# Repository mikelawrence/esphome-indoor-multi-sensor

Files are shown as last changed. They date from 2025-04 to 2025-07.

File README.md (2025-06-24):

# ESPHome Indoor Multi-Sensor

<p align="center">
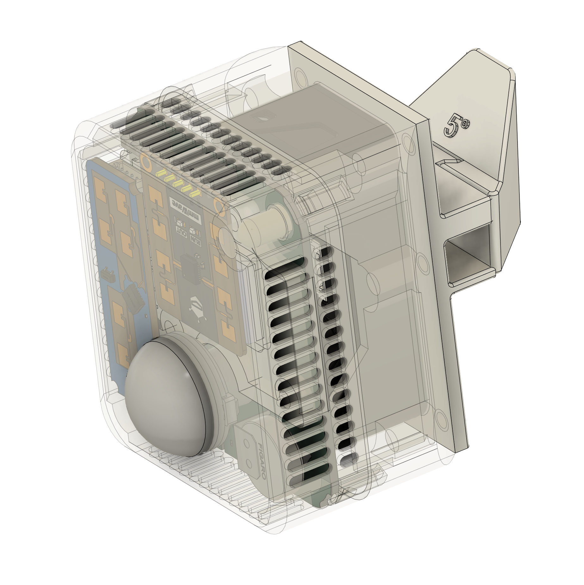
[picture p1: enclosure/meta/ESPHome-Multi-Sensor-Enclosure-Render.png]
  
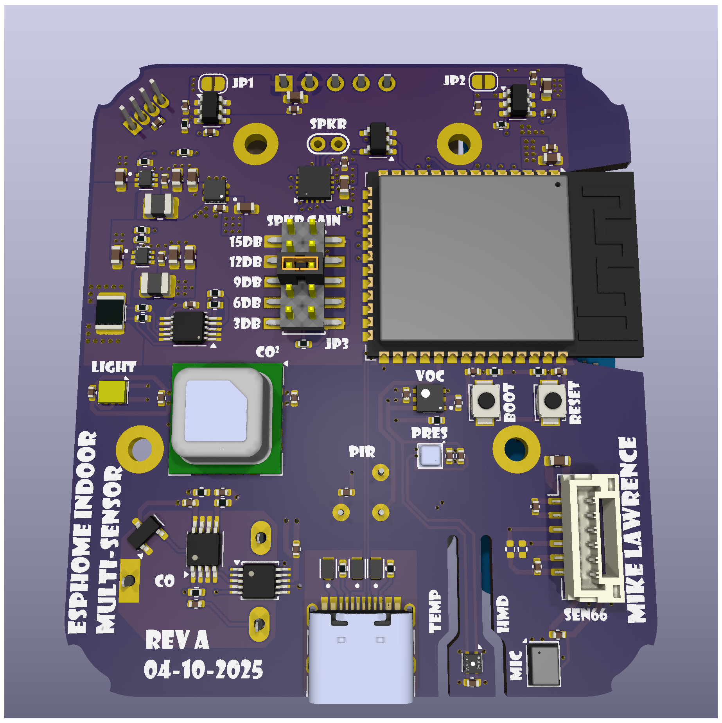
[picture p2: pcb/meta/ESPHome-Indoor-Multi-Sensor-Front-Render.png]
  
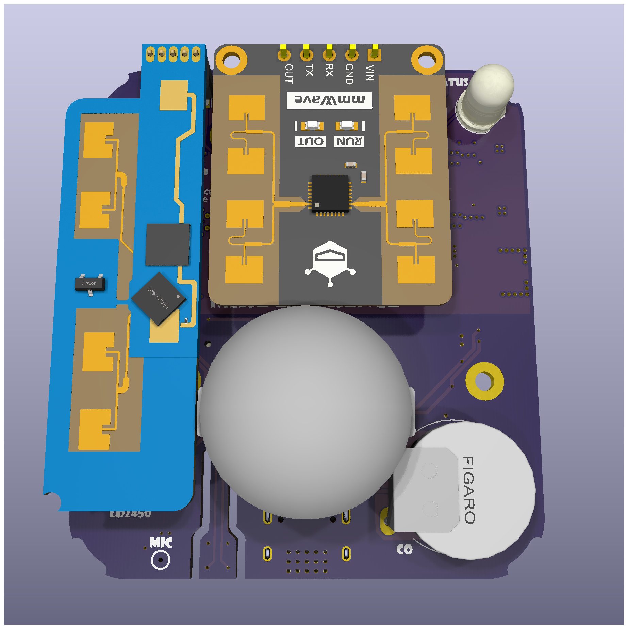
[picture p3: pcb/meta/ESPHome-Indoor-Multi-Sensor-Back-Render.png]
  
</p>

There are a lot of presence sensors using a combination of PIR and High Frequency Radar Human Presence Detectors to get a combination of quick response and low movement detection like when sleeping. Good examples of these types of sensor are the [Everything Presence One](https://shop.everythingsmart.io/products/everything-presence-one-kit) and [Roomsense IQ](https://www.roomsenselabs.com/). The later has a sensor module that you can add to support all sorts readings like Particular Matter (PM) Carbon Monoxide. But since I like to do everything myself. I started thinking about how I would approach this and more specifically what sensors did I want.

I settled on the following characteristics:

* ESP32-S3
* ESPHome software development
* USB-C Power
* Multiple options for Radar presence detection modules
  - Hi-Link LD2410B
  - Hi-Link LD2450
  - DFRobot C4001 (SEN609 and SEN610)
* PIR (Panasonic)
* Sensirion SEN66 All-in-One (Package A)
  - Temperature
  - Humidity
  - Particulate Matter (PM) 
  - CO₂
  - Volatile Organic Compound (VOC)
  - Nitrogen Oxide (NOX)
* Or individual Sensors (Package B)
  - Sensirion SHT4X Temperature and Humidity
  - Sensirion SCD4X CO₂
  - Sensirion SGP4X VOC and NOX
* Bosch BMP581 Pressure
* Figaro TGS5141 Carbon Monoxide (CO)
* AMS TSL2591 Light
* Microphone for sound levels
* A Speaker for alerts
* INA228 Power and Energy Monitor

## Status
* **Rev -** Has been fabricated and tested. I had JLCPCB fabricate the boards and I self assembled using a Home-Brew reflow oven by [Whizoo Controleo3](https://whizoo.com/). All circuits have been tested and found to be operational. 
* **Rev A** There was an issue with signal integrity on the I2C bus when communicating with the SEN66. To fix the problem I added stronger pullups and a new and dedicated I2C bus to the SEN66. Thus Rev A was born. I have not fabricated Rev A boards since I still have 6 Rev - boards left but the changes are minor and should be fine. Please let me know if you built Rev A and how it went.

## Design Decisions
### ESP32 and ESPHome
ESPHome is closely aligned with Home Assistant. In fact they are the same company. Home Assistant uses ESPHome for some of their hardware like the [Home Assistant Voice Preview Edition](https://www.home-assistant.io/voice-pe/) or [Bluetooth Proxy](https://esphome.io/components/bluetooth_proxy.html). I chose a newer ESP32-S3 for this design which also has Bluetooth support.

This project uses ESP32-S3-WROOM-2-N32R16V which has an enormous 32MB of flash and 16MB of octal PSRAM. These specs are way out of the normal range for an ESP32, so why? First I wanted to be able to store sounds directly on the unit itself mainly so it can sound out alerts even if Home Assistant is not connected. The PSRAM came along with the big Flash but it also has benefits. Sound pressure analysis likes more PSRAM and so does Bluetooth Proxying.

### Sensors
#### Radar based Human Presence Sensors
Both the Hi-Link sensors (LS2410B and LD2450) are supported by ESPHome directly but the DFRobot C4001 is not. I wrote an ESPHome External Component available [here](https://github.com/mikelawrence/ESPHome-Components?tab=readme-ov-file#esphome-c4001-external-component). The board has the LD2410 and LD2450 sharing the same physical space but the DFRobot C4001 can exist next to one of the LD sensors. I added circuitry so that you can choose which sensor to operate electrically. However enabling both simultaneously could result in strange behavior. After using the LD2450 for  bit I realized the the "just released" LD2450 ESPHome component has some short comings. Specifically there is no installation angle or flip-x-axis. So I added them in my version of the LD2450 ESPHome component [here] (https://github.com/mikelawrence/ESPHome-Components?tab=readme-ov-file#esphome-ld2450-external-component).

#### Sensor choices
The [SEN66](https://sensirion.com/products/catalog/SEN66) may be an expensive sensor package but it does it all, Temperature, Humidity, PM, CO₂, VOC and NOX. A tiny fan is primarily used for measuring PM but it also moves air by the temperature and humidity sensors making them fairly responsive. I call this Package A. If you choose not use the SEN66 you can populate the Package B individual sensors ([SHT4X](https://sensirion.com/media/documents/33FD6951/67EB9032/HT_DS_Datasheet_SHT4x_5.pdf), [SCD4X](https://sensirion.com/media/documents/48C4B7FB/67FE0194/CD_DS_SCD4x_Datasheet_D1.pdf) and [SGP4X](https://sensirion.com/media/documents/A056FE9C/61E970C2/Sensirion_Flyer_Gas_Sensors_Web.pdf)) to get Temperature, Humidity, CO₂, VOC and NOX. The only thing missing is PM.

#### Carbon Monoxide
For some reason CO sensors are not as common as CO₂ sensors. Most are expensive and have short life spans. The  Figaro TGS5141 is inexpensive and has a 10-year life span but it isn't a nice all-in-one with I2C interface. You have to add a transimpedance amplifier and then digitize the analog signal. I chose to add an ADS1115 16-bit ADC right next to the transimpedance amplifier instead of running analog signal across the board to the questionable ESP32 built in ADC. The ADS1115 also a has true differential Programmable Gain Amplifier on the input. This reduces the CO sensor circuit complexity. This sensor is not going to be very accurate but detection of CO in even low levels is probably a reason for concern. So even if not a safety sensor it can help.

I verified the CO circuit using CO Bump Gas. It doesn't calibrate, but it will prove that the sensor responds to the presence of CO. I used a small upside down container on my outside bench with the sensor I wanted to test inside. Squirting some bump gas inside with the thin straw showed that 4 out of 5 sensors responded to the gas. The 5'th that didn't respond had a solder bridge between two pins on the transimpedance amplifier. A quick removal of the solder bridge fixed the non-functioning sensor.

> [!WARNING]
> This CO sensor is not rated for safety nor is it particularly accurate. Use at your own risk! I still have UL listed (American) CO detectors as my main line of defense.

#### Pressure and Light
The [BMP581](https://www.bosch-sensortec.com/media/boschsensortec/downloads/datasheets/bst-bmp581-ds004.pdf) pressure sensor is primarily used as a barometric pressure sensor but it is sensitive enough for micro-pressure changes like when a door is closed. Pressure can also be used to compensate the CO₂ sensor in either the SEN6X or the SCD4X. Light is another measurement that may or may not be helpful but I included it. Keep in mind that this measurement is inside an enclosure thus has some significant limitations when it comes to accuracy.

#### Speaker and Microphone
The SEN66 takes up a lot of space so a small speaker is necessary. I choose a flat speaker from [Same Sky](https://www.sameskydevices.com/product/audio/speakers/miniature-(10-mm~40-mm)/cms-251437-24sp-x8) and started playing. My first attempts were pretty, flat, meaning these small speakers don't move a lot of air and in free space they have almost no volume. After doing some research it became clear, the speaker needs a enclosure. I was able to come up with a small 3D printed enclosure attached to the PCB itself. Man what a difference. This 2W speaker kicks some serious butt.

I threw in the microphone to measure sound levels. The intent is listen for noise as additional presence detection.

#### Power and Energy Monitor
The [INA228](https://www.ti.com/lit/ds/symlink/ina228.pdf) power and energy monitor can give instantaneous readings of voltage, current and power but it also measures energy over time (WHr).

### USB-C Power
I'm not using USB-C Power Delivery but I am expecting 5V @ 3A which is readily available if you have the right USB-C Power Brick. The PCB has the appropriate resistors on the CC pins which will request 5V @ 3A from a standard USB-C Power Brick. Testing shows slightly less than 1W for the Package A version and slightly less than 0.9 W for the Package B option as measured by the INA228. Quick measurements show about 8.1kWh/yr for Package A and 7.3kWh/yr for Package B. In Texas that is less than $1 per year.

## Enclosure
<p align="center">
  
</p>

More information is in the enclosure [README](enclosure/README.md) file.

## Operation
Expect an ESPHome YAML configuration soon.

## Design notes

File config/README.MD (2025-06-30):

# ESPHome Indoor Multi-Sensor Installation Configuration

Use this [webpage](https://mikelawrence.github.io/esphome-indoor-multi-sensor/) for installation and configuration.

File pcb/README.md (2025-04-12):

# ESPHome Indoor Multi-Sensor PCB
<p align="center">
  
  
</p>

The PCB is designed in [KiCad](https://www.kicad.org/). Fabrication and is tuned toward [JCLPCB](https://jlcpcb.com/). I chose not to use JLCPCB for assembly because they had a hard time with some the parts I included in this design. When I had the boards fabricated I also had them panelize two PCBs and produce a stencil for both for the panelized boards.

* **Rev -**: Is currently being fabricated. 

## Schematic
<p align="center">
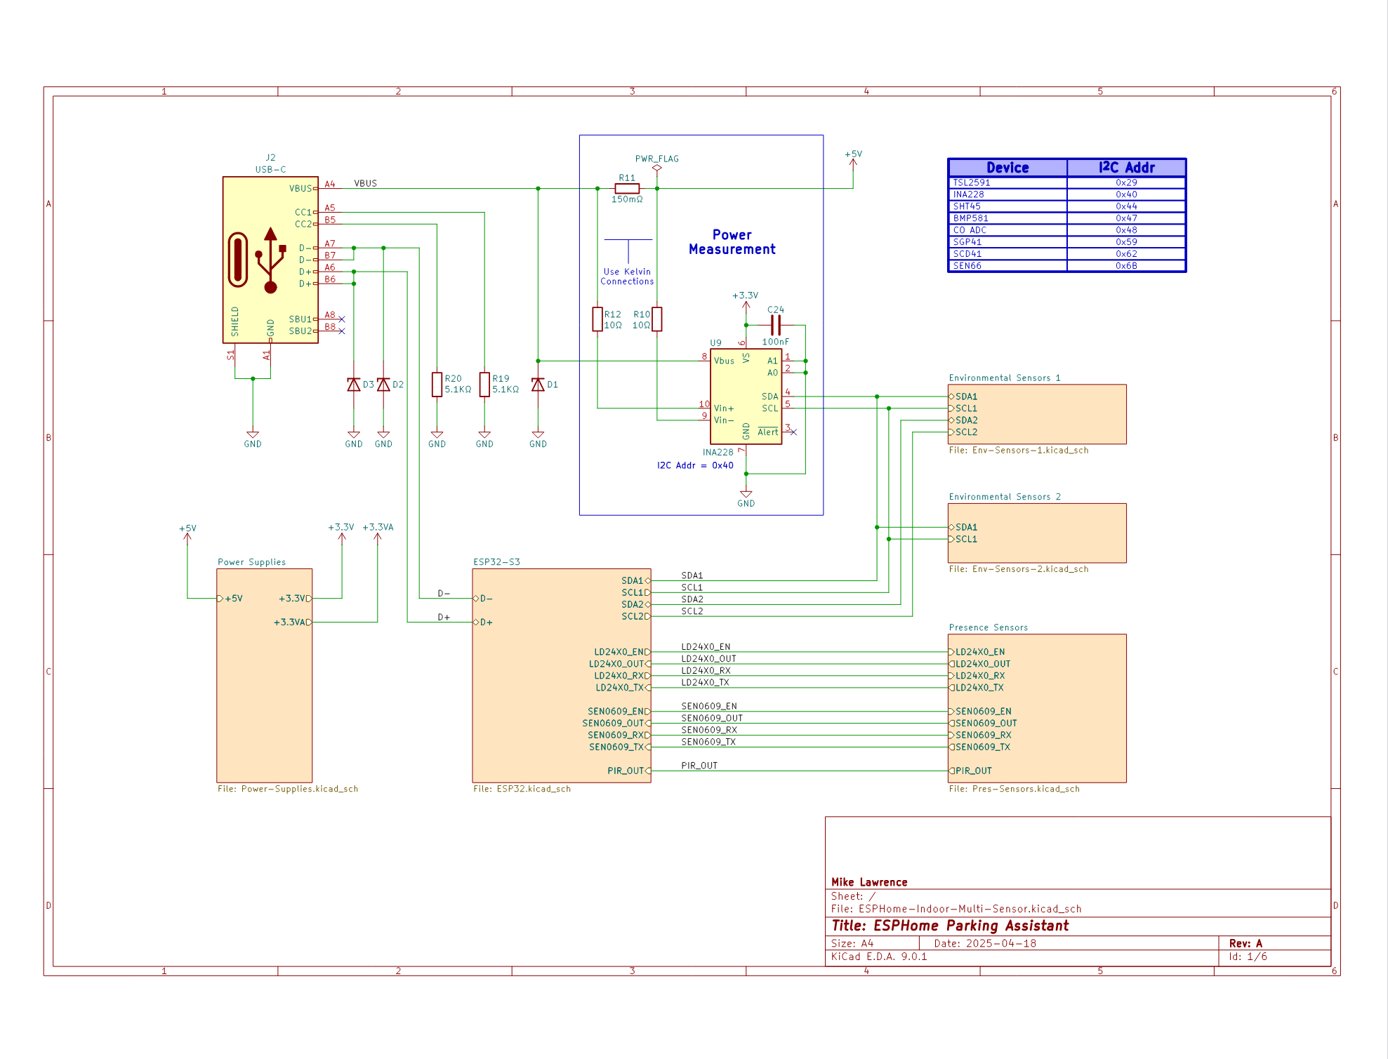
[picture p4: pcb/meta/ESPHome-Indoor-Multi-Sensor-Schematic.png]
     <br />
    Schematic
</p>

### Do Not Populate (DNP) Notes
When you use the SEN66 from Sensirion you don't need to install discrete sensor components ```U11```, ```U12```, ```U16```, ```C29```, ```C29```, ```C30```, ```C31``` or ```C43```.

## Bill of Materials
<p align="center">
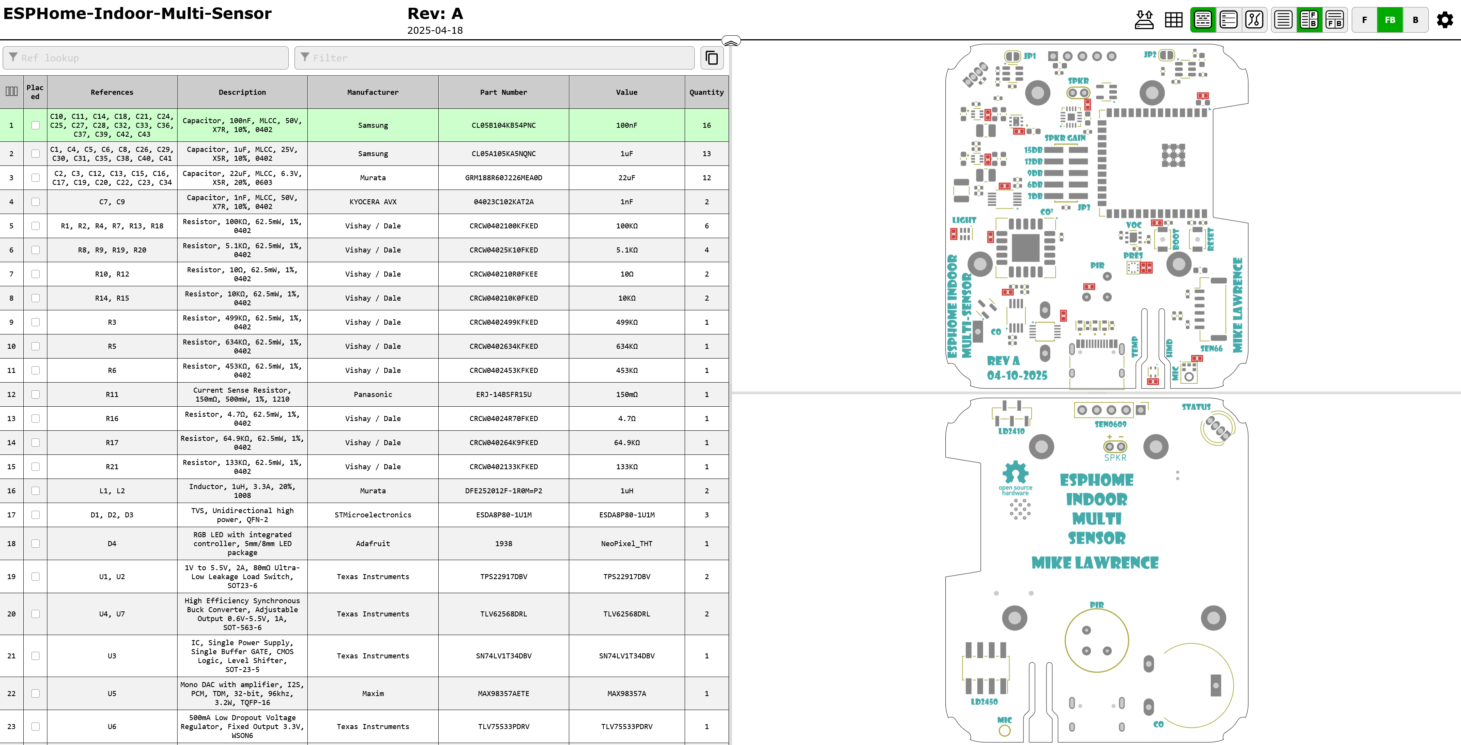
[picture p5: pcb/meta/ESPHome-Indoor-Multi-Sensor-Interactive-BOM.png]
     <br />
    Interactive BOM
</p>

## PCB Info
* 4 layer to support an additional ground plane and signal layer to reduce plane interruptions on the outer layers.
* There has been an attempt thermally isolate the SHT4X Temperature and Humidity Sensor but there are no guarantees.
* Dimensions are 52.5mm X 59.7mm.
* Requires oven reflow or hot air to assemble most components.

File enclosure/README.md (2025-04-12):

# ESPHome Parking Assistant Enclosure



This 3D printable enclosure is designed to go into a corner. It has a two-piece adjustable angle rear mount. Just change the ```Wall_Angle``` parameter. Both the speaker enclosure and back mount have TPU gaskets. The speaker gasket is to seal the enclosure and prevent vibrations from the speaker causing a buzzing sound. The TPU back mount gasket seals the SEN66 and provides a small amount of pressure to keep the SEN66 from moving.

The front body snaps into the back body and holds the PCB in place. A small cable connects the SEN66 to the PCB must be in place before snaps the bodies together.

The enclosure is designed in Fusion and is available [here](https://github.com/mikelawrence/ESPHome-Indoor-Multi-Sensor/raw/refs/heads/main/enclosure/ESPHome-Multi-Sensor-Enclosure.f3z).

If your are just looking for easy to print step file look in the ```3d-printing folder```. There a step file for each part and a nicely formatted Bambu Studio file with three plates ready to print.

## DFRobot C4001 SEN0609 Module
I couldn't find a step model of this Radar so I made one. Here is the [Fusion model](https://github.com/mikelawrence/ESPHome-Indoor-Multi-Sensor/raw/refs/heads/main/enclosure/DFRobot-C4001-SEN0609.f3z) and a [STEP model](https://github.com/mikelawrence/ESPHome-Indoor-Multi-Sensor/raw/refs/heads/main/enclosure/DFRobot-C4001-SEN0609.step).

## Hi-Link Electronics LD-2450 Module
The LD2450 Module I found were missing the front antennas and back header so I added these to the model from Hi-Link Electronics. Here is the [Fusion model](https://github.com/mikelawrence/ESPHome-Indoor-Multi-Sensor/raw/refs/heads/main/enclosure/HLK-LD2450-3D.f3z) and the [STEP model](https://github.com/mikelawrence/ESPHome-Indoor-Multi-Sensor/raw/refs/heads/main/enclosure/HLK-LD2450-3D.step).

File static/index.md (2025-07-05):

# ESPHome Indoor Multi-Sensor

You need to make two choices before programming the ESPHome Indoor Multi-Sensor. 

First is the Sensor package. You can either choose Package A, the Sensirion SEN6X sensor package which is an all-in-one sensor package. Or you can choose Package B which is a lower cost discrete sensor set that is missing particulate matter sensors. 

Next up is what type of radar sensor you plan on including. There are 4 options here, Hi Link LD2410 (My favorite), DFRobot C4001 (SEN0609 and SEN0610), Hi-Link LD2450 Multi-Target Multi-Zone (MTMZ) and the Hi-Link LD2450 Single-Target Single-Zone (STSZ). 

Each of these these builds include all supported sensors: pressure, light, sound level, power/energy monitor and speaker. If there are sensors you wish to not include, take control of the sensor and start configuring.

If you are really new to ESPHome I would recommend searching on Youtube for getting started videos.

## Installation

Use the buttons below to install pre-built firmware directly to your device via USB.

| Sensor Pkg | Radar LD2410 | Radar C4001 | Radar LD2450-MTMZ | Radar LD2450-STSZ |
|---|---|---|---|---|
| Pkg A | <esp-web-install-button manifest="firmware/sensor-pkg-a-ld2410.manifest.json"></esp-web-install-button> | <esp-web-install-button manifest="firmware/sensor-pkg-a-c4001.manifest.json"></esp-web-install-button> | <esp-web-install-button manifest="firmware/sensor-pkg-a-ld2450-mtmz.manifest.json"></esp-web-install-button> | <esp-web-install-button manifest="firmware/sensor-pkg-a-ld2450-stsz.manifest.json"></esp-web-install-button> |
| Pkg B | <esp-web-install-button manifest="firmware/sensor-pkg-b-ld2410.manifest.json"></esp-web-install-button> | <esp-web-install-button manifest="firmware/sensor-pkg-b-c4001.manifest.json"></esp-web-install-button> | <esp-web-install-button manifest="firmware/sensor-pkg-b-ld2450-mtmz.manifest.json"></esp-web-install-button> | <esp-web-install-button manifest="firmware/sensor-pkg-b-ld2450-stsz.manifest.json"></esp-web-install-button> |

<script type="module" src="https://unpkg.com/esp-web-tools@10/dist/web/install-button.js?module"></script> 

## Configuration

When you take control there are two sections you need to configure. In the ```substitutions:``` section you will find settings for many of the available sensors. Note: in yaml all substitutions are strings and should be in ```'single quotes'``` or  ```"double quotes"``` but the value may be interpreted as a float or a boolean value.

```yaml
substitutions:
  name: "sensor-pkg-a-c4001"
  friendly_name: "Indoor Multi-Sensor Pkg A Radar C4001"

  # Settings
  use_pir_in_presence: "true"
  # Status LED Configuration
  status_day_brightness: "0.5"
  status_night_brightness: "0.20"
  status_daytime_lux: "12.0"
  status_nighttime_lux: "7.0"
  # Temperature Configuration
  temperature_offset: "0.0"
  # Humidity Configuration
  humidity_offset: "0.0"
  # CO₂ Configuration
  co2_calibration_date: "Unknown"
  # CO Configuration
  co_temp_id: "temperature"
  co_offset: "0.0"
  co_sensitivity: "2.000e-9"
  co_manufacture_date: "Unknown"
  co_serial_number: "111111111111111111"
  # Automatically controlled Vent
  vent_ha_entity: fan.vent_id
  vent_use_humidity: "true"
  vent_use_co2: "true"
  vent_min_on_time: "15"
  vent_hum_on_trigger: "10.0"
  vent_hum_off_trigger: "2.5"
  vent_co2_on_trigger: "1100"
  vent_co2_off_trigger: "900"
```

The ```packages:``` section will allow you to disable sensors by commenting out it's included package. Note: do not comment out any Main Config Files.

```yaml
packages:
  remote_package_files:
    url: https://github.com/mikelawrence/esphome-indoor-multi-sensor
    refresh: 1h
    files:
      # Main Config Files
      - config/common/common.yaml
      - config/common/pkga-sen6x.yaml
      - config/common/radar-c4001.yaml

      # ADDITIONAL SENSORS
      # Carbon Dioxide (CO) - Figaro TGS5141 sensor
      - config/common/add-co.yaml
      # Energy Usage - INA2XX sensor to measure Voltage, Power and Energy Usage
      - config/common/add-ina2xx.yaml
      # Light Level - TSL2591 sensor
      - config/common/add-tsl2591.yaml
      # Barometric Pressure - BMP581 sensor
      - config/common/add-bmp581.yaml
      # Microphone - Adds Sound Level meter
      - config/common/add-microphone.yaml

      # FEATURES
      # SEN6X Pressure Compensation - Adds pressure compensation to SEN6X
      - config/common/feat-sen6x-press-comp.yaml
      # Automatic Vent - Use humidity and CO₂ control a bathroom vent
      - config/common/feat-auto-vent.yaml
```
### Settings

```yaml
  # Settings
  use_pir_in_presence: "true"
  # Status LED Configuration
  status_day_brightness: "0.5"
  status_night_brightness: "0.20"
  status_daytime_lux: "12.0"
  status_nighttime_lux: "7.0"
```

These are base sensor settings available for any configuration.

+ **use_pir_in_presence** (bool): You can disable the PIR motion detection from the presence sensor.
+ **status_day_brightness** (float): How bright is the Status LED during the day. Range is 0 to 1.0 where 1.0 means 100% brightness.
+ **status_night_brightness** (float): How bright is the Status LED during at night. Range is 0 to 1.0 where 1.0 means 100% brightness.
+ **status_daytime_lux** (float): The light level (lux) at which the Status LED will switch to daytime mode.
+ **status_nighttime_lux** (float): The light level (lux) at which the Status LED will switch to nighttime mode.
+ **temperature_offset** (float): The temperature sensor may have an offset due to environmental conditions. Use this to subtract out this error.
+ **humidity_offset** (float): The humidity sensor may have also have an offset. Use this to subtract out this error.
+ **co2_calibration_date** (string): Enter the last time the CO₂ was calibrated here and it will be reported as a text_sensor in the diagnostic section.

### Carbon Monoxide(CO) Configuration

```yaml
      # Carbon Dioxide (CO) - Figaro TGS5141 sensor
      - config/common/add-co.yaml
```

If you have included this package the CO sensor is enabled and there are substitutions you need to edit.

```yaml
  # CO Configuration
  co_temp_id: "temperature"
  co_offset: "0.0"
  co_sensitivity: "2.000e-9"
  co_manufacture_date: "Unknown"
  co_serial_number: "111111111111111111"
```

+ **co_temp_id** (ID): The accuracy of the CO sensor is improved with temperature compensation. This is the entity id of the temperature sensor to use.
+ **co_offset** (float): The CO sensor and circuit will have a offset. Use this to subtract out this error.
+ **co_sensitivity** (float): The CO has a default sensitivity of 2.000e-9 Amps/ppm. This should be the factory measured sensitivity as reported in the QR code on the sensor.
+ **co_manufacture_date** (float): From the QR code on the sensor. The sensor has a 10 year life expectancy. Reported as a text_sensor in the diagnostic section.
+ **co_serial_number** (float): From the QR code on the sensor. Not necessary but might come in handy down the road. Reported as a text_sensor in the diagnostic section.

### Automatically controlled Vent Configuration

```yaml
      # Automatic Vent - Use humidity and CO₂ control a bathroom vent
      - config/common/feat-auto-vent.yaml
```

If you have included this package the CO sensor is enabled and there are substitutions you need to edit.

```yaml
  # Automatically controlled Vent
  vent_ha_entity: fan.vent_id
  vent_use_humidity: "true"
  vent_use_co2: "true"
  vent_min_on_time: "15"
  vent_hum_on_trigger: "10.0"
  vent_hum_off_trigger: "2.5"
  vent_co2_on_trigger: "1100"
  vent_co2_off_trigger: "900"
```

+ **vent_ha_entity** (ID): This is the Home Assistant entity id of automatically controlled vent.
+ **vent_use_humidity** (bool): Enable humidity based control of the vent by setting this to ```true```.
+ **vent_use_co2** (bool): Enable CO₂ based control of the vent by setting this to ```true```.
+ **vent_min_on_time** (integer): This is the minimum on time for a vent for manual mode and how long the vent will stay on after the humidity or CO₂ returns to normal.
+ **vent_hum_on_trigger** (integer): This is the humidity level (%) rise from baseline that will turn on the vent. Baseline here is a fast exponential average (15 minutes). Showers usually have a sharp rise in humidity when first starting so a value of 10% rise in a few minutes is definitely a shower starting.
+ **vent_hum_off_trigger** (integer): This is the humidity level (%) from baseline that will turn off the vent. Baseline here is a slow exponential average (6ish hours). You want this number slightly above zero because sometimes the humidity level doesn't go back to where it was before a shower occurred quick enough. And even though the baseline average will eventually get there and cut off the vent it will have been on for hours.
+ **vent_co2_on_trigger** (integer): This is the CO₂ level that will cause the vent to turn on. Make 100-200 higher than ```vent_co2_off_trigger``` to give the vent a bit of hysteresis.
+ **vent_co2_off_trigger** (integer): This is the CO₂ level that will cause the vent to turn off.

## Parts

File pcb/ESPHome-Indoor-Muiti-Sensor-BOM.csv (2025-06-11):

Qty | Reference | Value | Description | DNP | Manufacturer | Part Number
13 | C1,C4,C5,C6,C8,C26,C29,C30,C31,C35,C38,C40,C41 | 1uF | Capacitor, 1uF, MLCC, 25V, X5R, 10%, 0402 |  | Samsung | CL05A105KA5NQNC
16 | C10,C11,C14,C18,C21,C24,C25,C27,C28,C32,C33,C36,C37,C39,C42,C43 | 100nF | Capacitor, 100nF, MLCC, 50V, X7R, 10%, 0402 |  | Samsung | CL05B104KB54PNC
12 | C2,C3,C12,C13,C15,C16,C17,C19,C20,C22,C23,C34 | 22uF | Capacitor, 22uF, MLCC, 6.3V, X5R, 20%, 0603 |  | Murata | GRM188R60J226MEA0D
2 | C7,C9 | 1nF | Capacitor, 1nF, MLCC, 50V, X7R, 10%, 0402 |  | KYOCERA AVX | 04023C102KAT2A
1 | D4 | NeoPixel_THT | RGB LED with integrated controller, 5mm/8mm LED package |  | Adafruit | 1938
3 | D1,D2,D3 | ESDA8P80-1U1M | TVS, Unidirectional high power, QFN-2 |  | STMicroelectronics | ESDA8P80-1U1M
1 | J1 | SEN66 | 6-Position, 1.25 mm pitch, Wire-to-Board connector |  | JST | BM06B-GHS-TBT
1 | J2 | USB-C | Connector, USB 2.0, 16P, Type-C, Receptacle |  | Phoenix Contact | 1332645
1 | J3 | SEN0609 | Generic connector, 2.54mm spacing, single row, 01x05 (TLW-105-06-T-S) |  | Samtec | CES-105-01-T-S
1 | J4 | LD2410 | Generic connector, 1.27mm spacing, single row, 01x05 |  | Samtec | RSM-105-02-S-S
1 | J5 | SPKR | Solder Holes for up to 24 ga wire |  | Same Sky | CMS-251437-24SP-X8
1 | J6 | LD2450 | Socket, 8 position, 2mm spacing, dual row, 02x04, SMT |  | Molex | 79109-1003
1 | JP3 | Gain | Header, 10 position, 2mm spacing, dual row, 02x05, SMT |  | Samtec | TMM-105-01-L-D-SM-P-TR
2 | L1,L2 | 1uH | Inductor, 1uH, 3.3A, 20%, 1008 |  | Murata | DFE252012F-1R0M=P2
1 | MK1 | ICS-43434 | TDK InvenSense MEMS Microphone, 24-bit I2S, 65 dBA SNR, LGA-6 |  | TDK InvenSense | ICS-43434
1 | Q1 | MMBFJ201 | 20mA min, 35V, 30mOhm max, 3-10V Vgs(off), N-Channel JFET, SOT-23 |  | Onsemi | MMBFJ201
1 | R3 | 499KΩ | Resistor, 499KΩ, 62.5mW, 1%, 0402 |  | Vishay / Dale | CRCW0402499KFKED
1 | R5 | 634KΩ | Resistor, 634KΩ, 62.5mW, 1%, 0402 |  | Vishay / Dale | CRCW0402634KFKED
1 | R6 | 453KΩ | Resistor, 453KΩ, 62.5mW, 1%, 0402 |  | Vishay / Dale | CRCW0402453KFKED
1 | R11 | 150mΩ | Current Sense Resistor, 150mΩ, 500mW, 1%, 1210 |  | Panasonic | ERJ-14BSFR15U
1 | R16 | 4.7Ω | Resistor, 4.7Ω, 62.5mW, 1%, 0402 |  | Vishay / Dale | CRCW04024R70FKED
1 | R17 | 64.9KΩ | Resistor, 64.9KΩ, 62.5mW, 1%, 0402 |  | Vishay / Dale | CRCW040264K9FKED
1 | R21 | 133KΩ | Resistor, 133KΩ, 62.5mW, 1%, 0402 |  | Vishay / Dale | CRCW0402133KFKED
6 | R1,R2,R4,R7,R13,R18 | 100KΩ | Resistor, 100KΩ, 62.5mW, 1%, 0402 |  | Vishay / Dale | CRCW0402100KFKED
2 | R10,R12 | 10Ω | Resistor, 10Ω, 62.5mW, 1%, 0402 |  | Vishay / Dale | CRCW040210R0FKEE
2 | R14,R15 | 10KΩ | Resistor, 10KΩ, 62.5mW, 1%, 0402 |  | Vishay / Dale | CRCW040210K0FKED
6 | R8,R9,R19,R20,R22,R23 | 5.1KΩ | Resistor, 5.1KΩ, 62.5mW, 1%, 0402 | DNP | Vishay / Dale | CRCW04025K10FKED
1 | SW1 | BOOT | Switch, SMD |  | Omron | B3U-1000P
1 | SW2 | RESET | Switch, SMD |  | Omron | B3U-1000P
1 | U3 | SN74LV1T34DBV | IC, Single Power Supply, Single Buffer GATE, CMOS Logic, Level Shifter, SOT-23-5 |  | Texas Instruments | SN74LV1T34DBV
1 | U5 | MAX98357A | Mono DAC with amplifier, I2S, PCM, TDM, 32-bit, 96khz, 3.2W, TQFP-16 |  | Maxim | MAX98357AETE
1 | U6 | TLV75533PDRV | 500mA Low Dropout Voltage Regulator, Fixed Output 3.3V, WSON6 |  | Texas Instruments | TLV75533PDRV
1 | U8 | ESP32-S3-WROOM-2-N32R16V | RF Module, ESP32-S3 SoC, Wi-Fi 802.11b/g/n, Bluetooth, BLE, 32-bit, 3.3V, onboard antenna, SMD |  | Espressif | ESP32-S3-WROOM-2-N32R16V
1 | U9 | INA228 | IC, High-Side or Low-Side Measurement, Bi-Directional Current and Power Monitor (0-85V) with I2C, SMBus-, and PMBus-Compatible Interface, VSSOP-10 |  | Texas Instruments | INA228AIDGSR
1 | U10 | TSL2591 | Light to digital converter, 2.7 to 3.6V Vdd, DFN-6 |  | AMS | TSL2591
1 | U11 | SGP41 | Indoor Air Quality Sensor, MOx based, DFN-6 |  | Sensirion | SGP41-D-R4
1 | U12 | SCD41 | Photoacoustic CO2 sensor, I2C, 2.4-5.5 V, High accuracy 400 - 5000 ppm |  | Sensirion | SCD41-D-R2
1 | U13 | BMP581 | Barometric Pressure Sensor, 24-bit, Low-power and Low-noise, SMD |  | Bosch Sensortec | BMP581
1 | U14 | MCP6042 | Dual Operational Amplifiers, Rail-to-Rail Input/Output, MSOP-8 |  | Microchip | MCP6042T-I/MS
1 | U15 | ADS1115 | Ultra-Small, Low-Power, I2C-Compatible, 860-SPS, 16-Bit ADCs With Internal Reference, Oscillator, and Programmable Comparator, VSSOP-10 |  | Texas Instruments | ADS1115IDGS
1 | U16 | SHT45 | Digital Humidity and Temperature Sensor, ±1%RH, ±0.1°C, I2C, 1.08-3.6V, 16bit, DFN-4 |  | Sensirion | SHT45-AD1B-R2
1 | U17 | EKMC1603111 | Passive Infrared (PIR) Motion Sensor, THT |  | Panasonic | EKMC1603111
1 | U18 | TGS5141 | Carbon Monoxide Sensor, Long life, THT |  | Figaro | TGS5141-P00
2 | U1,U2 | TPS22917DBV | 1V to 5.5V, 2A, 80mΩ Ultra-Low Leakage Load Switch, SOT23-6 |  | Texas Instruments | TPS22917DBV
2 | U4,U7 | TLV62568DRL | High Efficiency Synchronous Buck Converter, Adjustable Output 0.6V-5.5V, 1A, SOT-563-6 |  | Texas Instruments | TLV62568DRL

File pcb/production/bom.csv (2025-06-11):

Designator | Footprint | Quantity | Value | LCSC Part #
C1, C26, C29, C30, C31, C35, C38, C4, C40, C41, C5, C6, C8 | 0402 | 13 | 1uF | C52923
C10, C11, C14, C18, C21, C24, C25, C27, C28, C32, C33, C36, C37, C39, C42, C43 | 0402 | 16 | 100nF | C307331
C12, C13, C15, C16, C17, C19, C2, C20, C22, C23, C3, C34 | 0603 | 12 | 22uF | C77042
C7, C9 | 0402 | 2 | 1nF
D1, D2, D3 | TVS_ESDA25P35-1U1M | 3 | ESDA8P80-1U1M
D4 | LED_D5.0mm-4_RGB | 1 | NeoPixel_THT
J1 | JST_GH_BM06B-GHS-TBT_1x06-1MP_P1.25mm_Vertical | 1 | SEN66 | C189892
J2 | USB_C_Receptacle_HRO_TYPE-C-31-M-12 | 1 | USB-C
J3 | PinHeader_1x05_P2.54mm_Vertical | 1 | SEN0609
J4 | PinSocket_1x05_P1.27mm_Vertical_SMD_Pin1Right | 1 | LD2410
J5 | PinHeader_1x02_P2.00mm_Vertical | 1 | SPKR
J6 | PinSocket_2x04_P2.00mm_Vertical_SMD | 1 | LD2450
JP3 | SAMTEC_TMM-105-01-X-D-SM | 1 | Gain
L1, L2 | 1008 | 2 | 1uH | C435392
MK1 | InvenSense_ICS-43434-6_3.5x2.65mm | 1 | ICS-43434
Q1 | SOT-23 | 1 | MMBFJ201 | C891687
R1, R13, R18, R2, R4, R7 | 0402 | 6 | 100KΩ
R10, R12 | 0402 | 2 | 10Ω
R11 | 1210 | 1 | 150mΩ
R14, R15 | 0402 | 2 | 10KΩ
R16 | 0402 | 1 | 4.7Ω
R17 | 0402 | 1 | 64.9KΩ
R19, R20, R8, R9 | 0402 | 4 | 5.1KΩ
R21 | 0402 | 1 | 133KΩ
R3 | 0402 | 1 | 499KΩ
R5 | 0402 | 1 | 634KΩ
R6 | 0402 | 1 | 453KΩ
SW1 | SW_SPST_B3U-1000P-B | 1 | BOOT | C231329
SW2 | SW_SPST_B3U-1000P-B | 1 | RESET | C231329
U1, U2 | SOT-23-6 | 2 | TPS22917DBV | C2681320
U10 | AMS_TSL25911FN | 1 | TSL2591
U11 | XCDR_SGP40-D-R4 | 1 | SGP41
U12 | Sensirion_SCD4x-1EP_10.1x10.1mm_P1.25mm_EP4.8x4.8mm | 1 | SCD41
U13 | BMP581 | 1 | BMP581
U14 | MSOP-8_3x3mm_P0.65mm | 1 | MCP6042 | C627438
U15 | TSSOP-10_3x3mm_P0.5mm | 1 | ADS1115 | C37593
U16 | Sensirion_DFN-4_1.5x1.5mm_P0.8mm_SHT4x_NoCentralPad | 1 | SHT45
U17 | EKMC163111 | 1 | EKMC1603111
U18 | TGS-5141 | 1 | TGS5141
U3 | SOT-23-5 | 1 | SN74LV1T34DBV | C100024
U4, U7 | SOT50P160X60-6N | 2 | TLV62568DRL | C398372
U5 | TQFN-16-1EP_3x3mm_P0.5mm_EP1.23x1.23mm | 1 | MAX98357A
U6 | VREG_TLV75533PDRVR | 1 | TLV75533PDRV
U8 | ESP32-S3-WROOM-2 | 1 | ESP32-S3-WROOM-2-N32R16V
U9 | VSSOP-10_3x3mm_P0.5mm | 1 | INA228 | C2887910

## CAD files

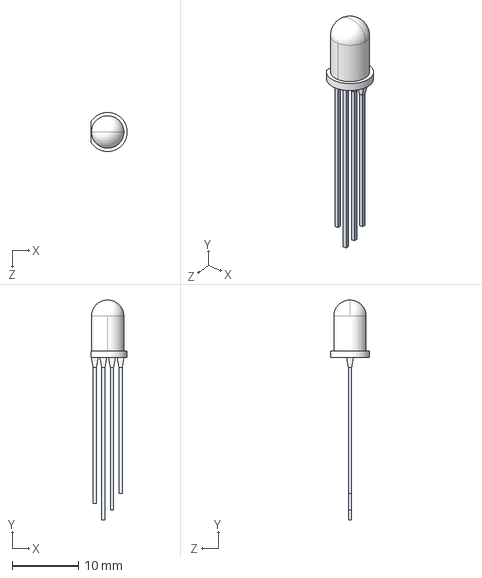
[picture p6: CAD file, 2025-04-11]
pcb/3dmodels/5mm RGB LED--3DModel-STEP-269445.STEP
5.50 x 33.2 x 5.89 mm

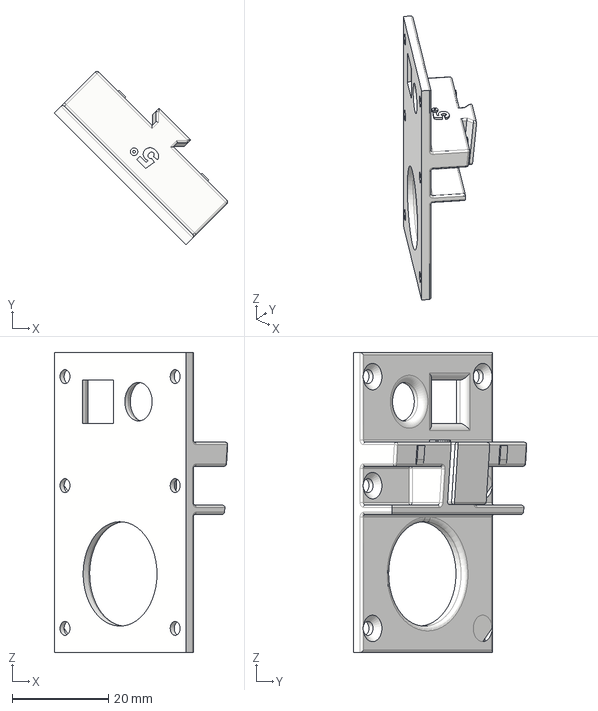
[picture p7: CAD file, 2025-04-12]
enclosure/3d-printing/ESPHome-Multi-Sensor-Enclosure-Back-Mount-5°.step
36.0 x 36.0 x 62.2 mm

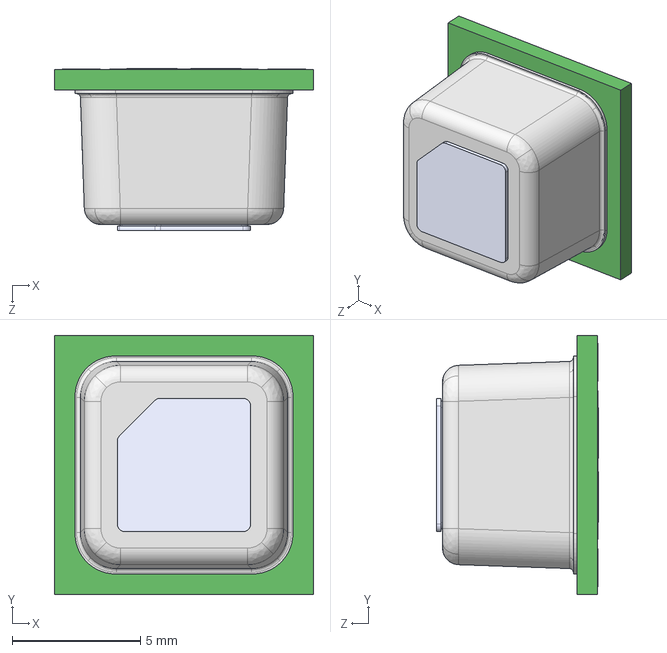
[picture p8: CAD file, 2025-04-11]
pcb/3dmodels/SCD41-D-R2--3DModel-STEP-369182.STEP
10.1 x 10.1 x 6.31 mm

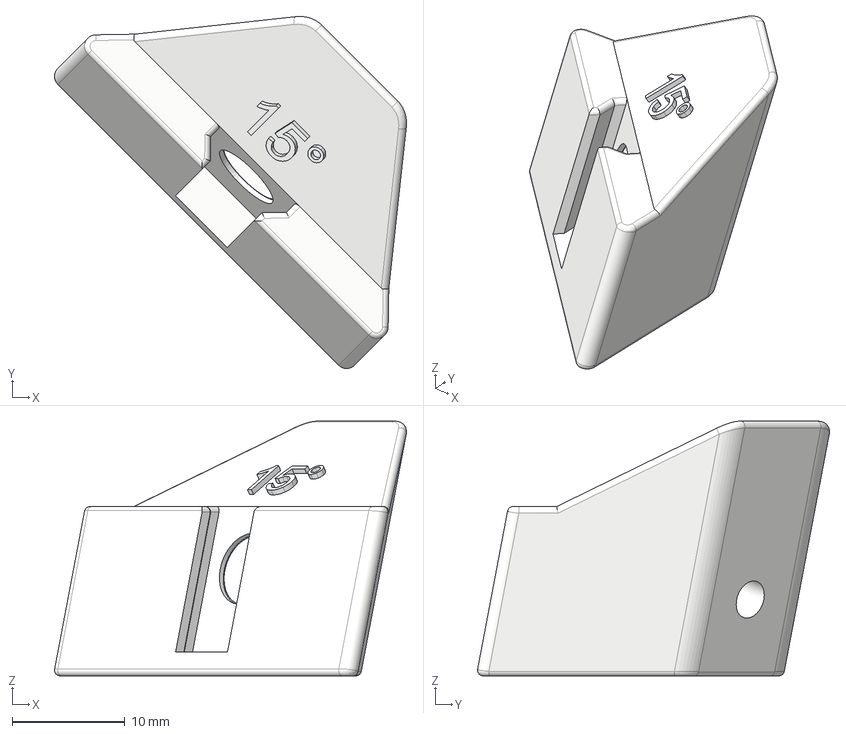
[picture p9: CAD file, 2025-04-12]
enclosure/3d-printing/ESPHome-Multi-Sensor-Enclosure-Corner-Mount-15°.step
31.2 x 31.2 x 22.6 mm

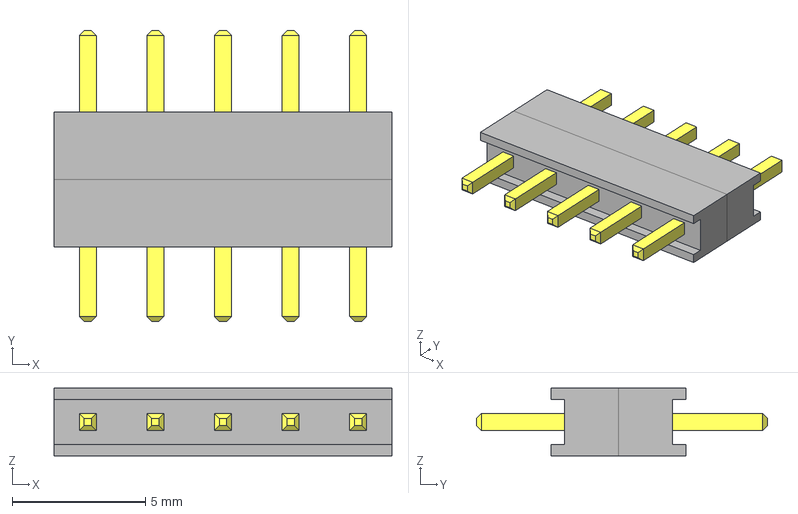
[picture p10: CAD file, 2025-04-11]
pcb/3dmodels/DW-05-07-T-S-200.stp
12.7 x 10.9 x 2.54 mm
ZW-05-07-G-S-200-110bbody
ZW-05-07-G-S-200-110_pins
ZW-05-07-G-S-200-110_top_body

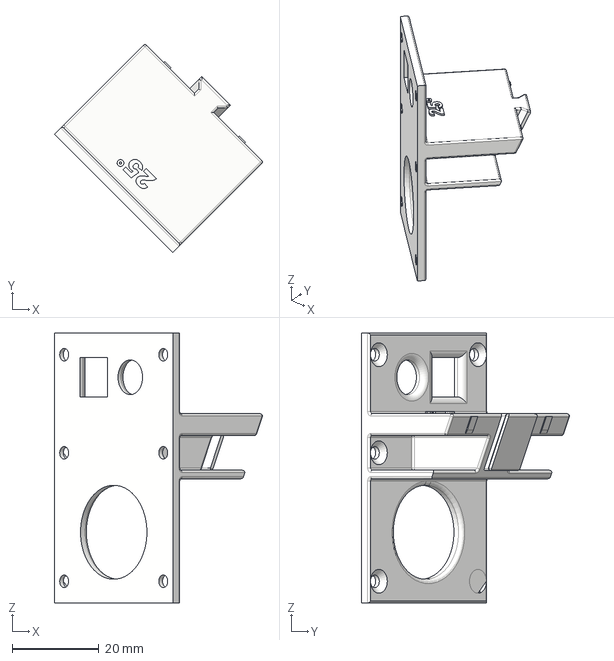
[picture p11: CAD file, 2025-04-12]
enclosure/3d-printing/ESPHome-Multi-Sensor-Enclosure-Back-Mount-25°.step
47.9 x 47.9 x 62.2 mm

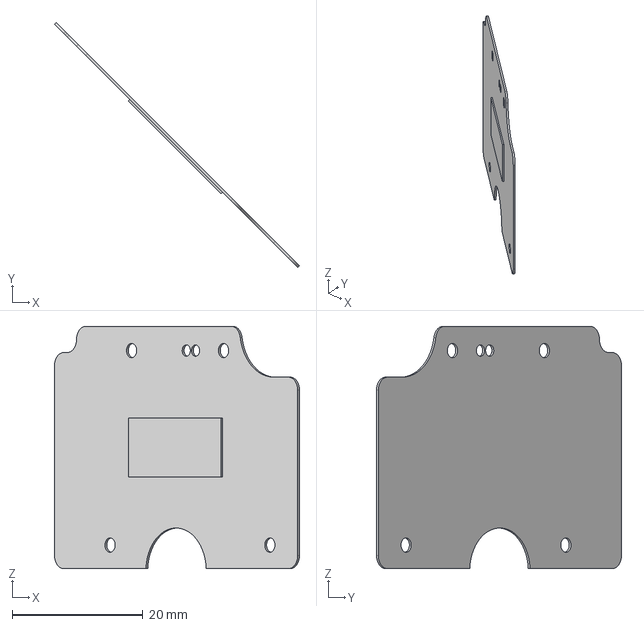
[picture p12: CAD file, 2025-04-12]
enclosure/3d-printing/ESPHome-Multi-Sensor-Enclosure-Speaker-Gasket-25mmx14mm.step
37.4 x 37.4 x 37.0 mm

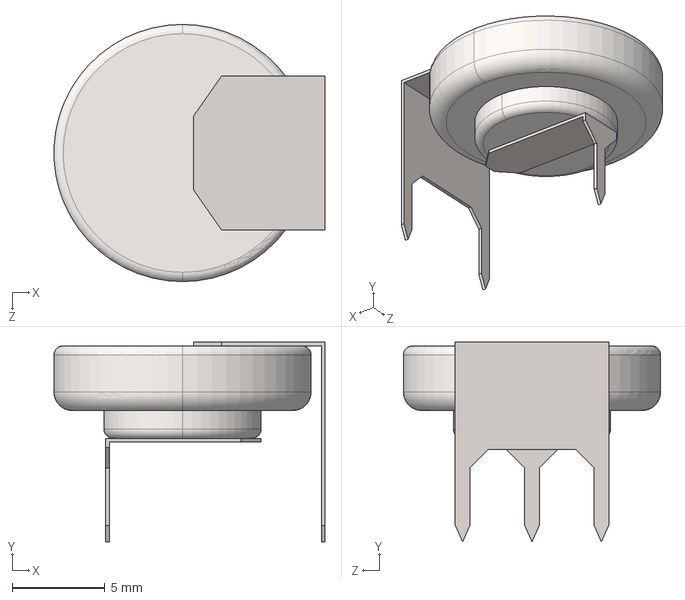
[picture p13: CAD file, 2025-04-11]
pcb/3dmodels/User Library-TGS5141.STEP
14.6 x 10.8 x 13.9 mm

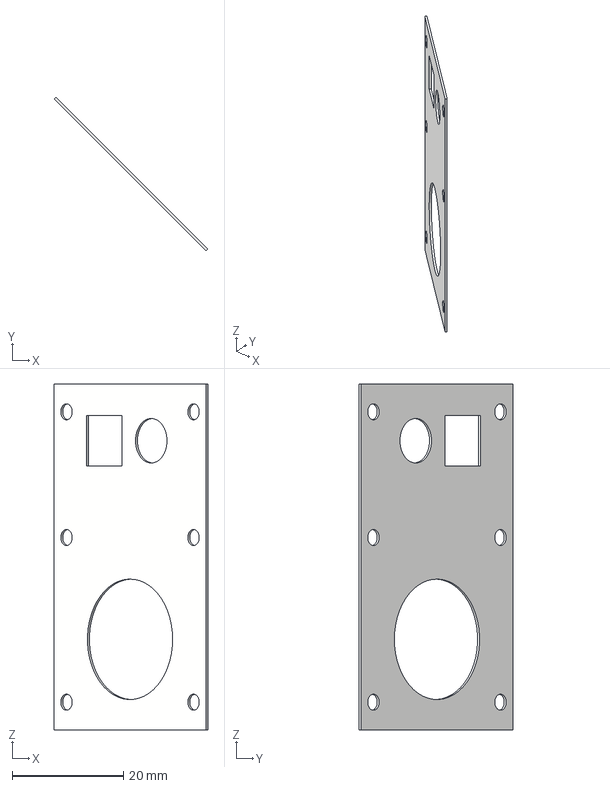
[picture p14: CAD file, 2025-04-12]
enclosure/3d-printing/ESPHome-Multi-Sensor-Enclosure-Back-Mount-Gasket.step
27.6 x 27.6 x 62.2 mm

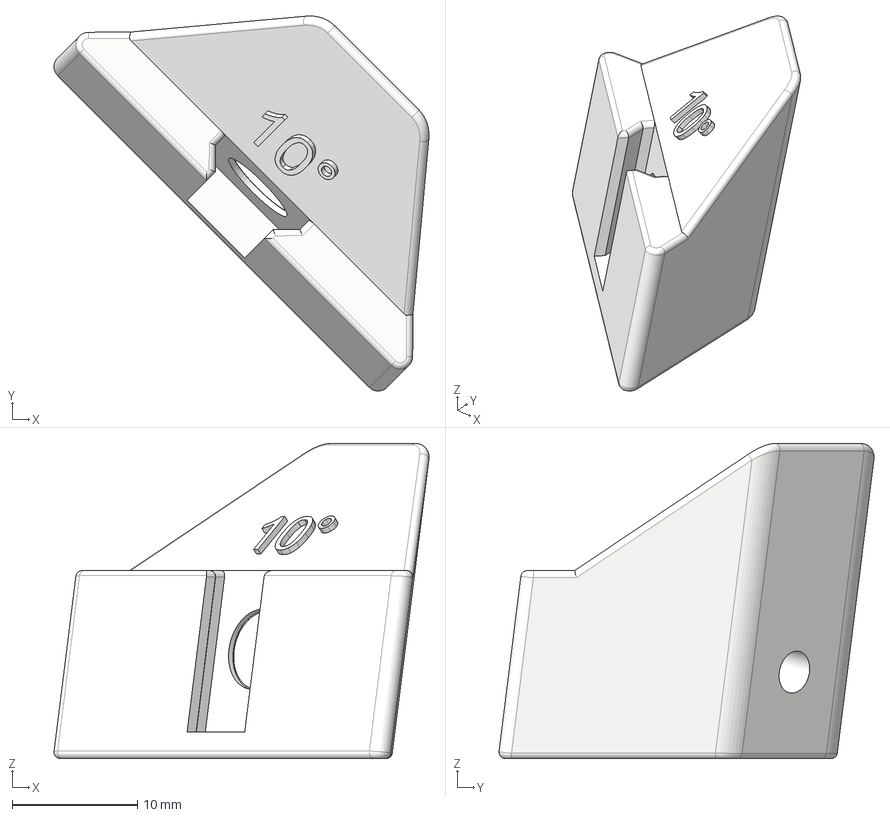
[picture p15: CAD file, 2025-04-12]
enclosure/3d-printing/ESPHome-Multi-Sensor-Enclosure-Corner-Mount-10°.step
29.9 x 29.9 x 25.1 mm

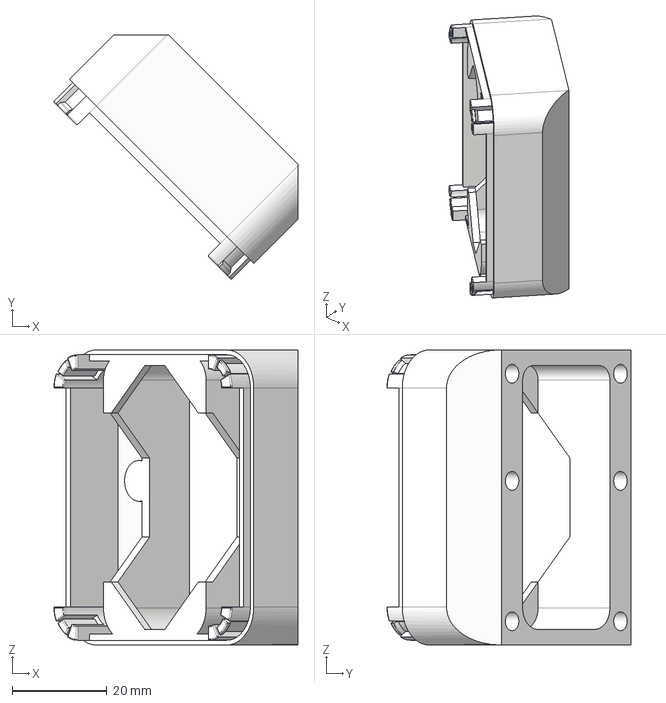
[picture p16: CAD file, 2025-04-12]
enclosure/3d-printing/ESPHome-Multi-Sensor-Enclosure Back Body.step
51.4 x 51.4 x 62.2 mm

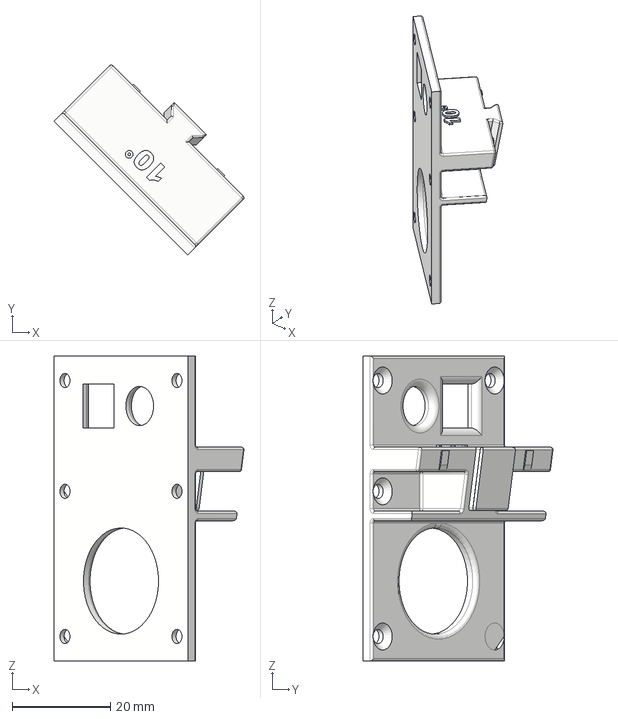
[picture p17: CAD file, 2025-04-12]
enclosure/3d-printing/ESPHome-Multi-Sensor-Enclosure-Back-Mount-10°.step
38.7 x 38.7 x 62.2 mm

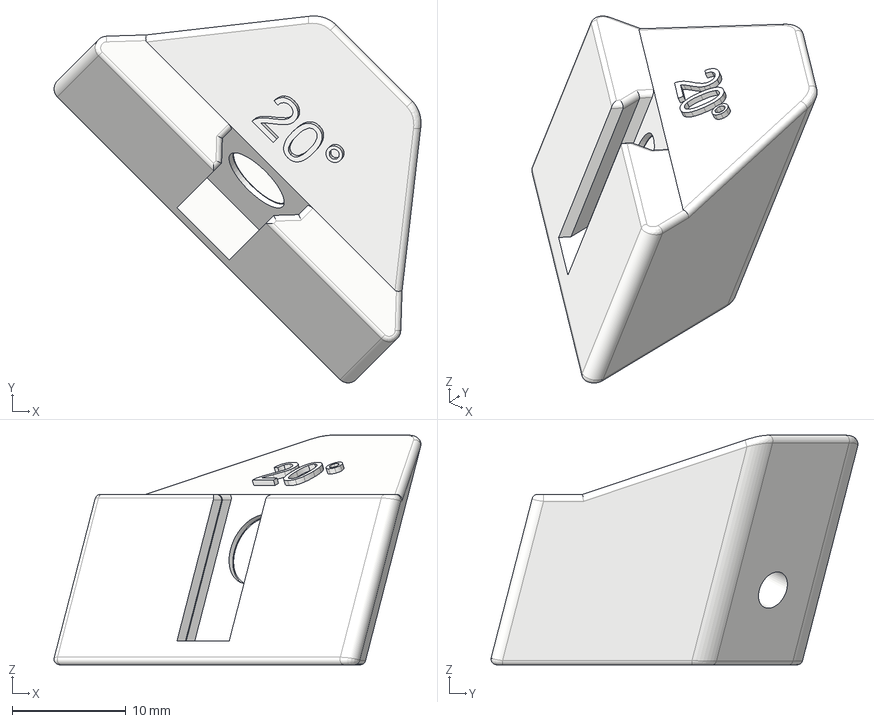
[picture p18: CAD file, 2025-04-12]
enclosure/3d-printing/ESPHome-Multi-Sensor-Enclosure-Corner-Mount-20°.step
32.3 x 32.3 x 20.2 mm

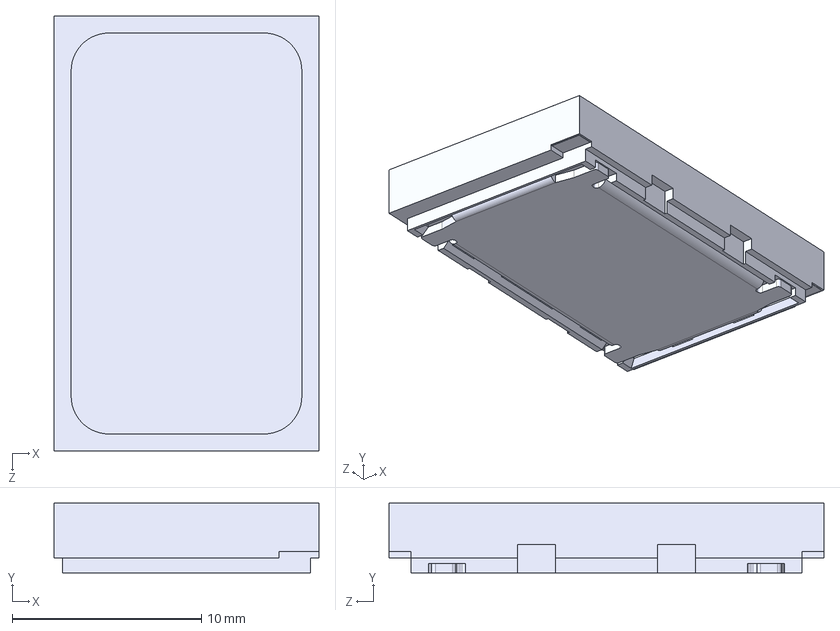
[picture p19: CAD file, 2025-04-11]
pcb/3dmodels/Same_Sky_CMS-321437-24SP-X8.step
14.0 x 3.70 x 23.0 mm

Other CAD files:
enclosure/3d-printing/ESPHome-Multi-Sensor-Enclosure-Bambu-Studio.3mf
pcb/3dmodels/DW-05-07-T-S-240.stp
enclosure/3d-printing/ESPHome-Multi-Sensor-Enclosure-Back-Mount-15°.step
pcb/3dmodels/RSM-105-02-S-S.stp
enclosure/3d-printing/ESPHome-Multi-Sensor-Enclosure Front Body.step
enclosure/3d-printing/ESPHome-Multi-Sensor-Enclosure-Back-Mount-20°.step
enclosure/3d-printing/ESPHome-Multi-Sensor-Enclosure-Corner-Mount-25°.step
enclosure/3d-printing/ESPHome-Multi-Sensor-Enclosure-Corner-Mount-5°.step
enclosure/3d-printing/ESPHome-Multi-Sensor-Enclosure-Speaker-25mmx14mm.step
pcb/3dmodels/55510-308TRLF--3DModel-STEP-554624.STEP
pcb/3dmodels/791091003.stp
pcb/3dmodels/86730.stp
pcb/3dmodels/CES-105-01-T-S.stp
pcb/3dmodels/DW-05-08-T-S-250.stp
pcb/3dmodels/ESP32-S3-MINI-1-N8--3DModel-STEP-1.STEP
pcb/3dmodels/HLK-2410B.step
pcb/3dmodels/MAX98357-TQFN-16.step
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

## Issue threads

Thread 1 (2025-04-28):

Cost question

fredmorais, 2025-04-28:
Hey,

I think this project looks really good and I am really looking forward to try it, but I have a question regards cost: can you share how much it cost to make the PCB + components?

It would be really helpful to understand how much each sensor will cost!

Best,

mikelawrence, 2025-04-28:
I didn't design for cost so this is not cheap. A full cost workup would take too long but here is some quick info.

10 PCBs from JLCPCB $40
SEN66 is about $55
ESP32 $7 You could choose a cheaper ESP32
C4001 $13
LD2410 $10
LD2450 $15
PIR $10
Pressure $6
SCD41 $25
SGP41 $10
SHT45 $6
CO sensor + circuit is about $15

Odds and ends is about $50 to $75

You can grab the BOM and import it to Mouser or Digikey to get a better idea of component cost.
Newark has the best price on the SEN66. If you use the SEN66 you don't need the SCD41, SGP41 or SHT45.

BTW I have checked out everything but the CO circuit. I have some bump gas coming with 200 ppm of CO to see if I can get the CO sensor to measure something. Also the Sound Level Meter software I was planning on using doesn't play well with other sound devices. Right now I can't get the Sound Level Meter and Speaker working at the same time. Both work separately though.

mikelawrence, 2025-04-28:
Something else to realize the SEN66 probably shouldn't be used in a bathroom, too much humidity. My wife also uses hairspray. I can't even begin to imagine what that would do to the sensor.

fredmorais, 2025-04-28:
Thanks for the info! One last question: I have been getting into circuit design but I am not able to reach this conclusion: if I removed some sensors that I do not find interesting (pressure, PIR, for example), would the sensor still work normally?

mikelawrence, 2025-04-29:
Yes, but as you remove sensors from the board you will need to remove them from the ESPHome YAML too. There isn't any one sensor that is dependent on another. You can remove the INA228 power sensor too but be sure to either keep R11 or short it. You can save money in other ways. Choose only one MMWave sensor, remove the power switch circuits and short the appropriate JPx.

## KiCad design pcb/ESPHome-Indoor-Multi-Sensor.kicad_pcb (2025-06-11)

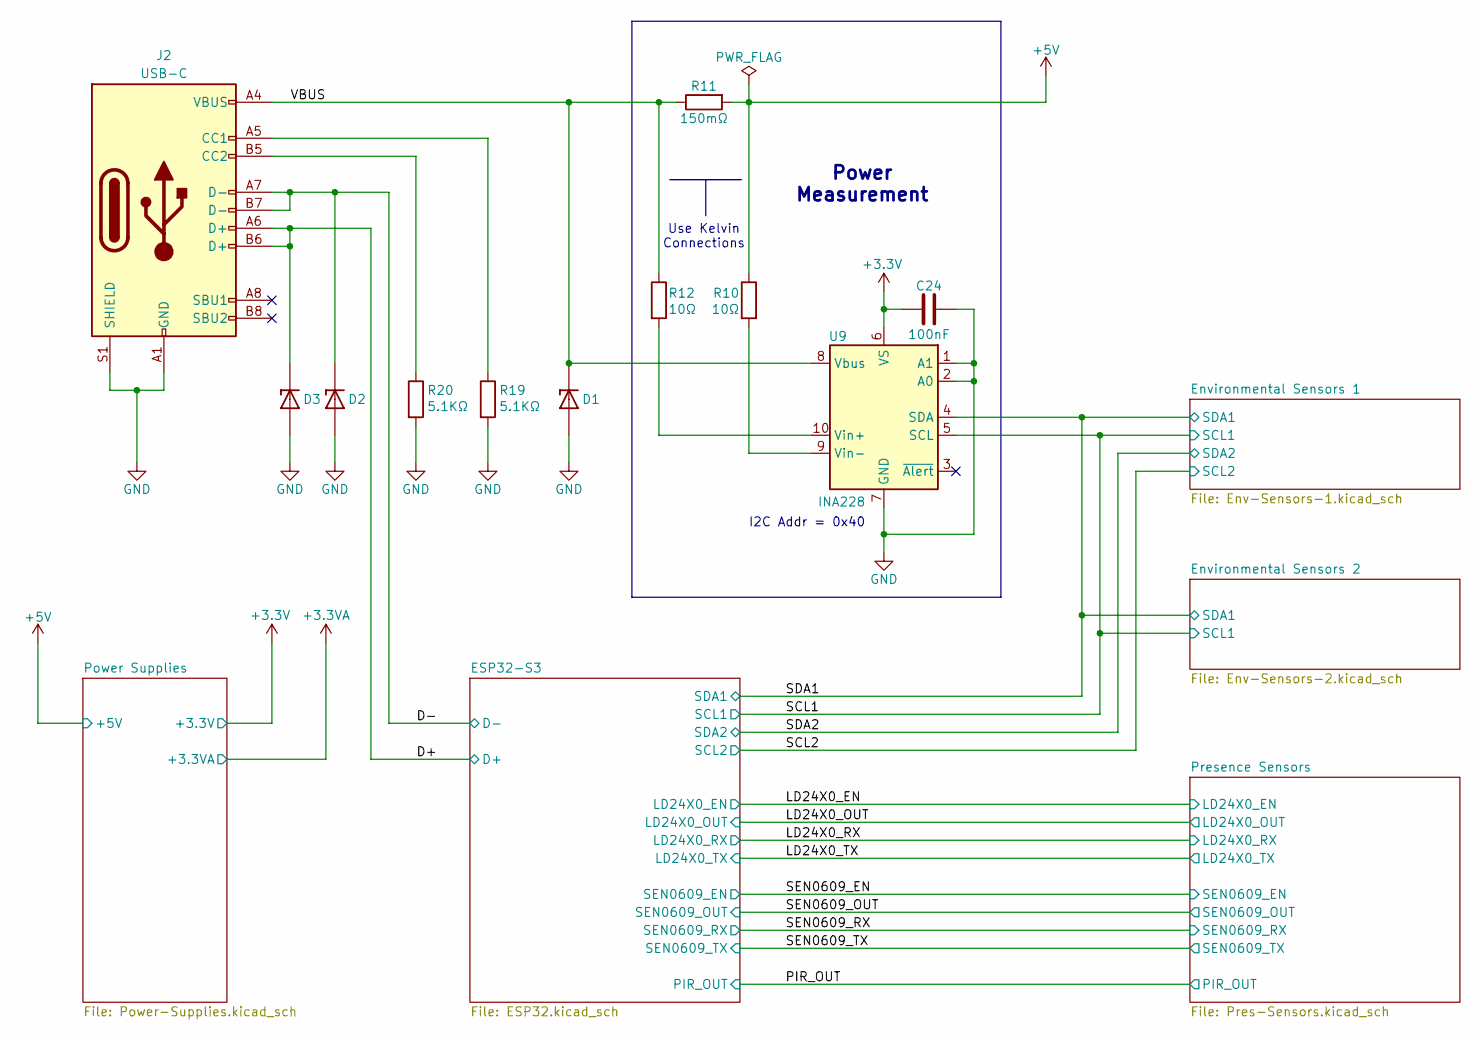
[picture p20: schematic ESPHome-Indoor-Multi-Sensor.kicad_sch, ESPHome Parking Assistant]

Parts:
C24: 100nF; C_0402_1005Metric; Part Number CL05B104KB54PNC
D1, D2, D3: ESDA8P80-1U1M; TVS_ESDA25P35-1U1M; Part Number ESDA8P80-1U1M
J2: USB-C; USB_C_Receptacle_HRO_TYPE-C-31-M-12; Part Number 1332645
R10, R12: 10Ω; R_0402_1005Metric; Part Number CRCW040210R0FKEE
R11: 150mΩ; R_1210_3225Metric; Part Number ERJ-14BSFR15U
R19, R20: 5.1KΩ; R_0402_1005Metric; Part Number CRCW04025K10FKED
U9: INA228; VSSOP-10_3x3mm_P0.5mm; Part Number INA228AIDGSR

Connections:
+3.3V: C24.2, U9.6 (VS); also elsewhere on the board
+5V: R10.1, R11.2; also elsewhere on the board
/D+: D3.C, J2.A6 (D+), J2.B6 (D+); also elsewhere on the board
/D-: D2.C, J2.A7 (D-), J2.B7 (D-); also elsewhere on the board
/SCL1: U9.5 (SCL); also elsewhere on the board
/SDA1: U9.4 (SDA); also elsewhere on the board
/VBUS: D1.C, J2.A4 (VBUS), J2.A9 (VBUS), J2.B4 (VBUS), J2.B9 (VBUS), R11.1, R12.1, U9.8 (Vbus)
GND: C24.1, D1.A, D2.A, D3.A, J2.A1 (GND), J2.A12 (GND), J2.B1 (GND), J2.B12 (GND), J2.S1 (SHIELD), R19.2, R20.2, U9.1 (A1), U9.2 (A0), U9.7 (GND); also elsewhere on the board
unnamed: J2.A5 (CC1), R19.1
unnamed: J2.B5 (CC2), R20.1
unnamed: R12.2, U9.10 (Vin+)
unnamed: R10.2, U9.9 (Vin-)

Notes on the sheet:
I2C Addr = 0x40
Power Measurement
Use Kelvin Connections

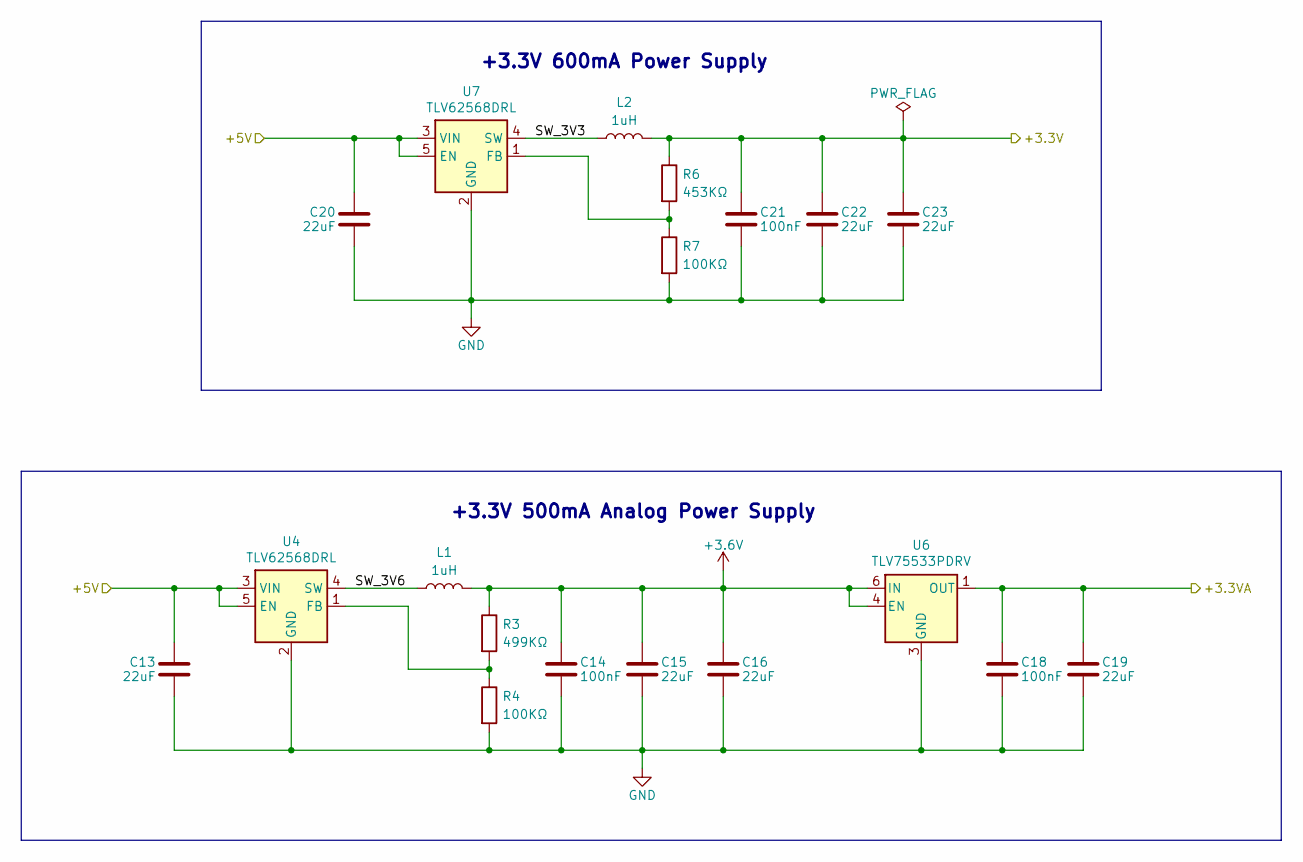
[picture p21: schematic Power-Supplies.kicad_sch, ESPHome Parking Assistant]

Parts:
C13, C15, C16, C19, C20, C22, C23: 22uF; C_0603_1608Metric; Part Number GRM188R60J226MEA0D
C14, C18, C21: 100nF; C_0402_1005Metric; Part Number CL05B104KB54PNC
L1, L2: 1uH; L_1008_2520Metric; Part Number DFE252012F-1R0M=P2
R3: 499KΩ; R_0402_1005Metric; Part Number CRCW0402499KFKED
R4, R7: 100KΩ; R_0402_1005Metric; Part Number CRCW0402100KFKED
R6: 453KΩ; R_0402_1005Metric; Part Number CRCW0402453KFKED
U4, U7: TLV62568DRL; SOT50P160X60-6N; Part Number TLV62568DRL
U6: TLV75533PDRV; VREG_TLV75533PDRVR; Part Number TLV75533PDRV

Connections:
+3.3V: C21.2, C22.1, C23.1, L2.2, R6.1; also elsewhere on the board
+3.3VA: C18.2, C19.1, U6.1 (OUT); also elsewhere on the board
+3.6V: C14.2, C15.1, C16.1, L1.2, R3.1, U6.4 (EN), U6.6 (IN)
+5V: C13.1, C20.1, U4.3 (VIN), U4.5 (EN), U7.3 (VIN), U7.5 (EN); also elsewhere on the board
/Power Supplies/SW_3V3: L2.1, U7.4 (SW)
/Power Supplies/SW_3V6: L1.1, U4.4 (SW)
GND: C13.2, C14.1, C15.2, C16.2, C18.1, C19.2, C20.2, C21.1, C22.2, C23.2, R4.2, R7.2, U4.2 (GND), U6.3 (GND), U6.7 (GND), U7.2 (GND); also elsewhere on the board
unnamed: R3.2, R4.1, U4.1 (FB)
unnamed: R6.2, R7.1, U7.1 (FB)

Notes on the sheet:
+3.3V 600mA Power Supply
+3.3V 500mA Analog Power Supply

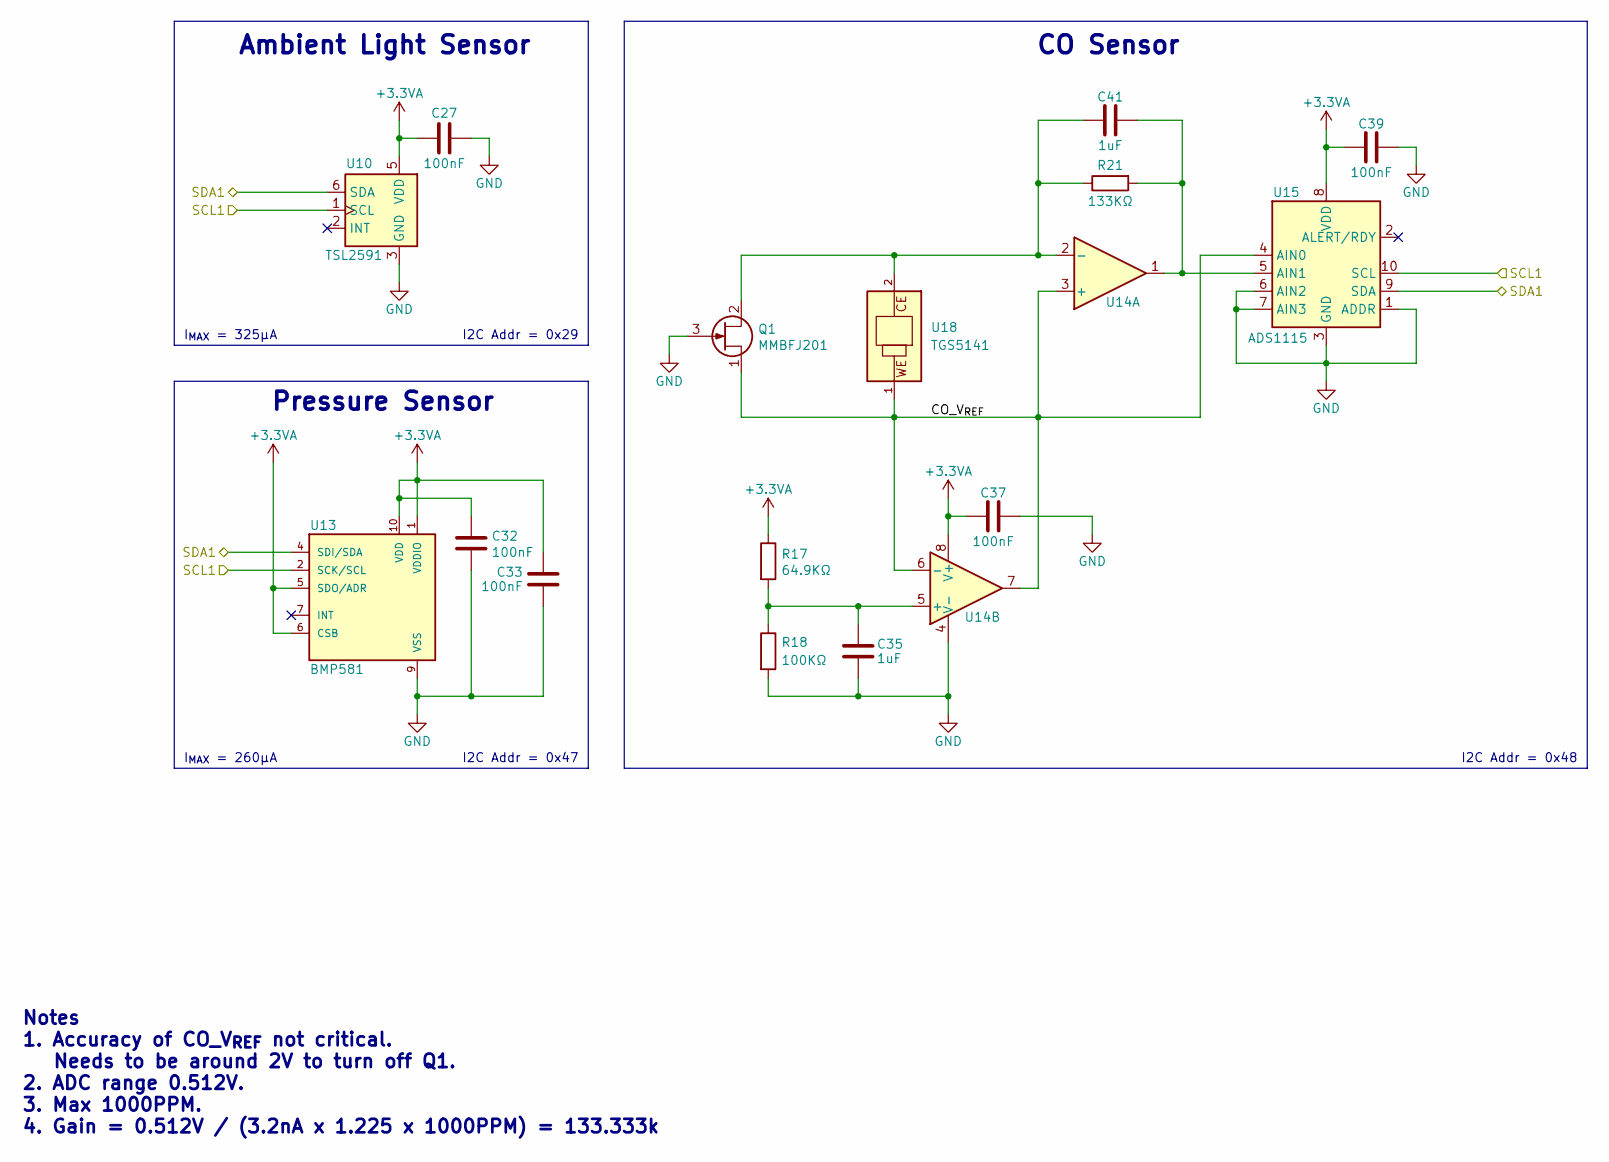
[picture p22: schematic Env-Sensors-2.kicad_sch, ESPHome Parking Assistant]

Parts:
C27, C32, C33, C37, C39: 100nF; C_0402_1005Metric; Part Number CL05B104KB54PNC
C35, C41: 1uF; C_0402_1005Metric; Part Number CL05A105KA5NQNC
Q1: MMBFJ201; SOT-23; Part Number MMBFJ201
R17: 64.9KΩ; R_0402_1005Metric; Part Number CRCW040264K9FKED
R18: 100KΩ; R_0402_1005Metric; Part Number CRCW0402100KFKED
R21: 133KΩ; R_0402_1005Metric; Part Number CRCW0402133KFKED
U10: TSL2591; AMS_TSL25911FN; Part Number TSL2591
U13: BMP581; Part Number BMP581
U14: MCP6042; MSOP-8_3x3mm_P0.65mm; Part Number MCP6042T-I/MS
U15: ADS1115; TSSOP-10_3x3mm_P0.5mm; Part Number ADS1115IDGS
U18: TGS5141; TGS-5141; Part Number TGS5141-P00

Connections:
+3.3VA: C27.2, C32.1, C33.1, C37.1, C39.1, R17.1, U10.5 (VDD), U13.1 (VDDIO), U13.5 (SDO/ADR), U13.6 (CSB), U13.10 (VDD), U14.8 (V+), U15.8 (VDD); also elsewhere on the board
/Environmental Sensors 2/CO_V_{REF}: Q1.1 (D), U14.3 (+), U14.6 (-), U14.7, U15.4 (AIN0), U18.1 (WE)
/SCL1: U10.1 (SCL), U13.2 (SCK/SCL), U15.10 (SCL); also elsewhere on the board
/SDA1: U10.6 (SDA), U13.4 (SDI/SDA), U15.9 (SDA); also elsewhere on the board
GND: C27.1, C32.2, C33.2, C35.2, C37.2, C39.2, Q1.3 (G), R18.2, U10.3 (GND), U13.3 (VSS), U13.8 (VSS), U13.9 (VSS), U14.4 (V-), U15.1 (ADDR), U15.3 (GND), U15.6 (AIN2), U15.7 (AIN3); also elsewhere on the board
unnamed: C41.1, Q1.2 (S), R21.1, U14.2 (-), U18.2 (CE)
unnamed: C35.1, R17.2, R18.1, U14.5 (+)
unnamed: C41.2, R21.2, U14.1, U15.5 (AIN1)

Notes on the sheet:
I_{MAX} = 260µA
CO Sensor
I2C Addr = 0x29
I2C Addr = 0x48
Notes 1. Accuracy of CO_V_{REF} not critical. Needs to be around 2V to turn off Q1. 2. ADC range 0.512V. 3. Max 1000PPM. 4. Gain = 0.512V / (3.2nA x 1.225 x 1000PPM) = 133.333k
Ambient Light Sensor
I_{MAX} = 325µA
I2C Addr = 0x47
Pressure Sensor

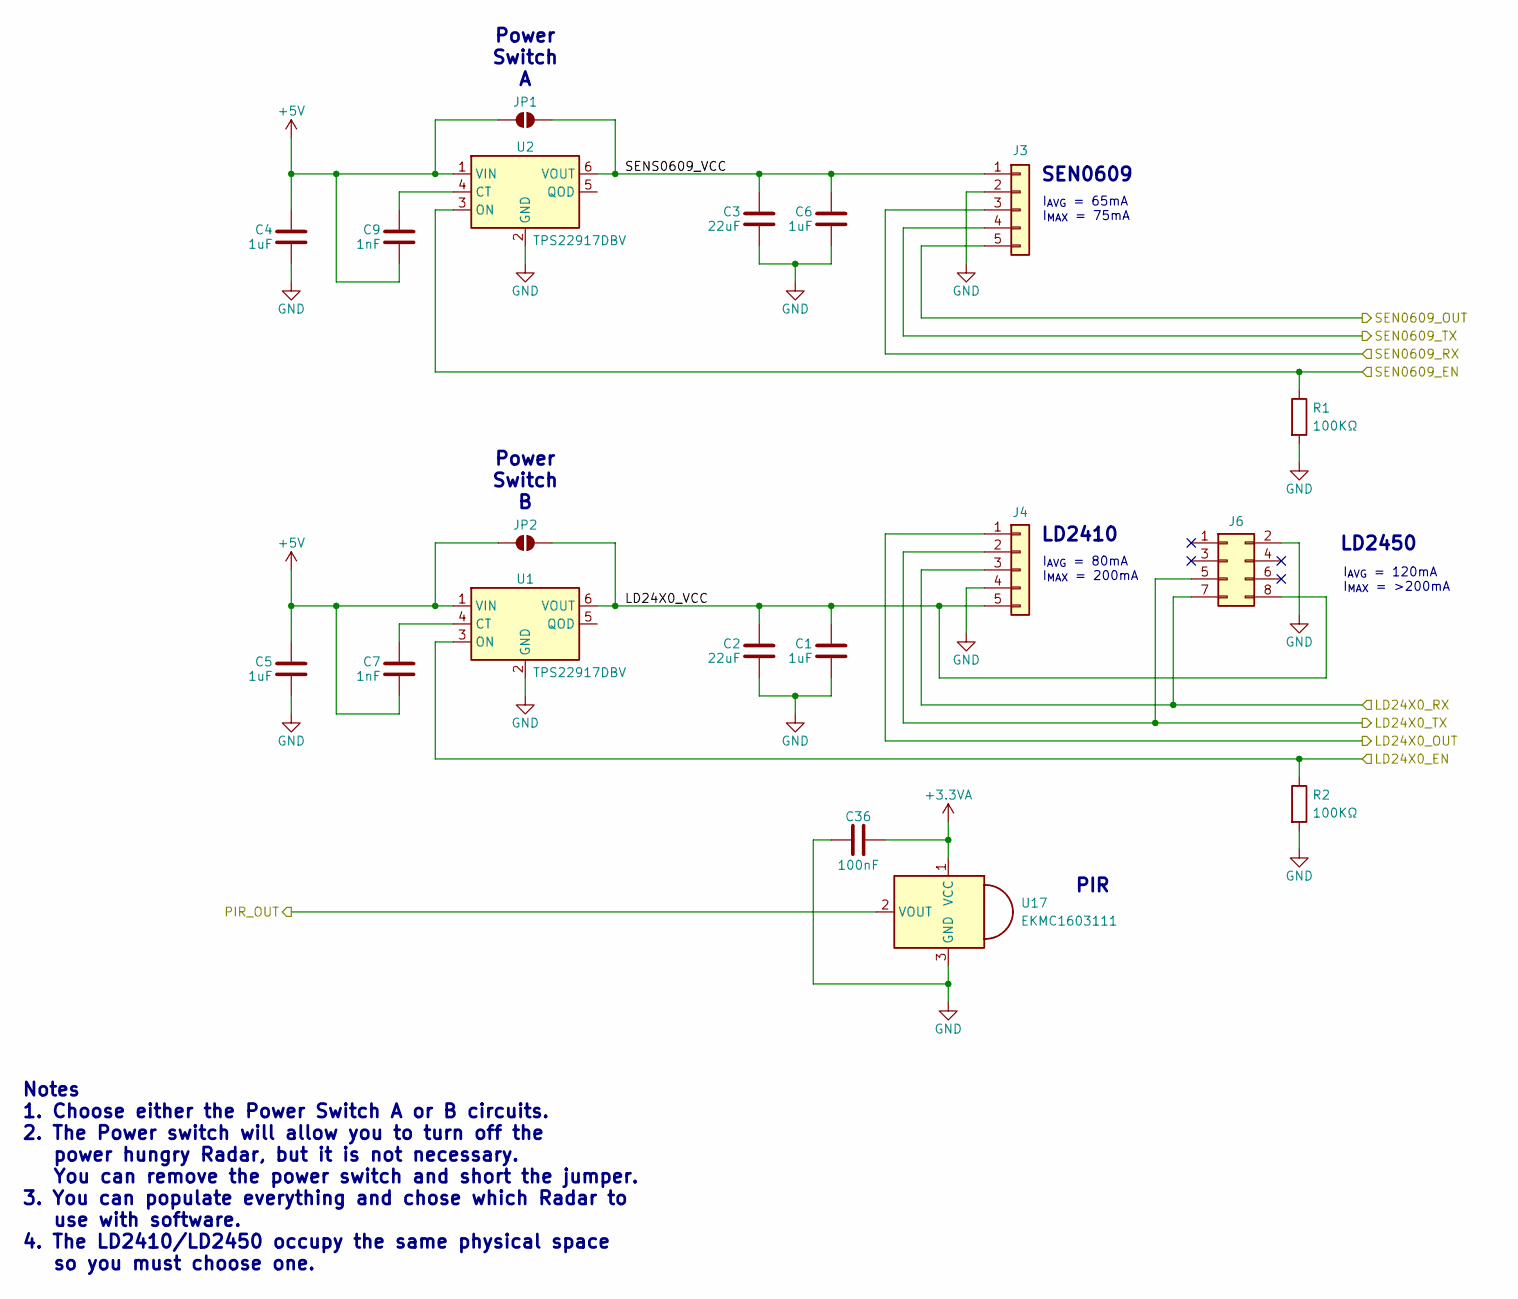
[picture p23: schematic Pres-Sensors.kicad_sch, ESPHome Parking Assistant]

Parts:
C1, C4, C5, C6: 1uF; C_0402_1005Metric; Part Number CL05A105KA5NQNC
C2, C3: 22uF; C_0603_1608Metric; Part Number GRM188R60J226MEA0D
C7, C9: 1nF; C_0402_1005Metric; Part Number 04023C102KAT2A
C36: 100nF; C_0402_1005Metric; Part Number CL05B104KB54PNC
J3: SEN0609; PinHeader_1x05_P2.54mm_Vertical; Part Number CES-105-01-T-S
J4: LD2410; PinSocket_1x05_P1.27mm_Vertical_SMD_Pin1Right; Part Number RSM-105-02-S-S
J6: LD2450; PinSocket_2x04_P2.00mm_Vertical_SMD; Part Number 79109-1003
JP1, JP2: SolderJumper-2_P1.3mm_Open_RoundedPad1.0x1.5mm
R1, R2: 100KΩ; R_0402_1005Metric; Part Number CRCW0402100KFKED
U1, U2: TPS22917DBV; SOT-23-6; Part Number TPS22917DBV
U17: EKMC1603111; EKMC163111; Part Number EKMC1603111

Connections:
+3.3VA: C36.2, U17.1 (VCC); also elsewhere on the board
+5V: C4.1, C5.1, C7.2, C9.2, JP1.1 (A), JP2.1 (A), U1.1 (VIN), U2.1 (VIN); also elsewhere on the board
/LD24X0_EN: R2.1, U1.3 (ON); also elsewhere on the board
/LD24X0_OUT: J4.1; also elsewhere on the board
/LD24X0_RX: J4.3, J6.7; also elsewhere on the board
/LD24X0_TX: J4.2, J6.5; also elsewhere on the board
/PIR_OUT: U17.2 (VOUT); also elsewhere on the board
/Presence Sensors/LD24X0_VCC: C1.1, C2.1, J4.5, J6.8, JP2.2 (B), U1.6 (VOUT)
/Presence Sensors/SENS0609_VCC: C3.1, C6.1, J3.1, JP1.2 (B), U2.6 (VOUT)
/SEN0609_EN: R1.1, U2.3 (ON); also elsewhere on the board
/SEN0609_OUT: J3.5; also elsewhere on the board
/SEN0609_RX: J3.3; also elsewhere on the board
/SEN0609_TX: J3.4; also elsewhere on the board
GND: C1.2, C2.2, C3.2, C4.2, C5.2, C6.2, C36.1, J3.2, J4.4, J6.2, R1.2, R2.2, U1.2 (GND), U2.2 (GND), U17.3 (GND); also elsewhere on the board
unnamed: C7.1, U1.4 (CT)
unnamed: C9.1, U2.4 (CT)

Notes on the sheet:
Power Switch B
Power Switch A
I_{AVG} = 65mA I_{MAX} = 75mA
LD2450
LD2410
I_{AVG} = 80mA I_{MAX} = 200mA
PIR
SEN0609
Notes 1. Choose either the Power Switch A or B circuits. 2. The Power switch will allow you to turn off the power hungry Radar, but it is not necessary. You can remove the power switch and short the jumper. 3. You can populate everything and chose which Radar to use with software. 4. The LD2410/LD2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
I_{AVG} = 120mA I_{MAX} = >200mA

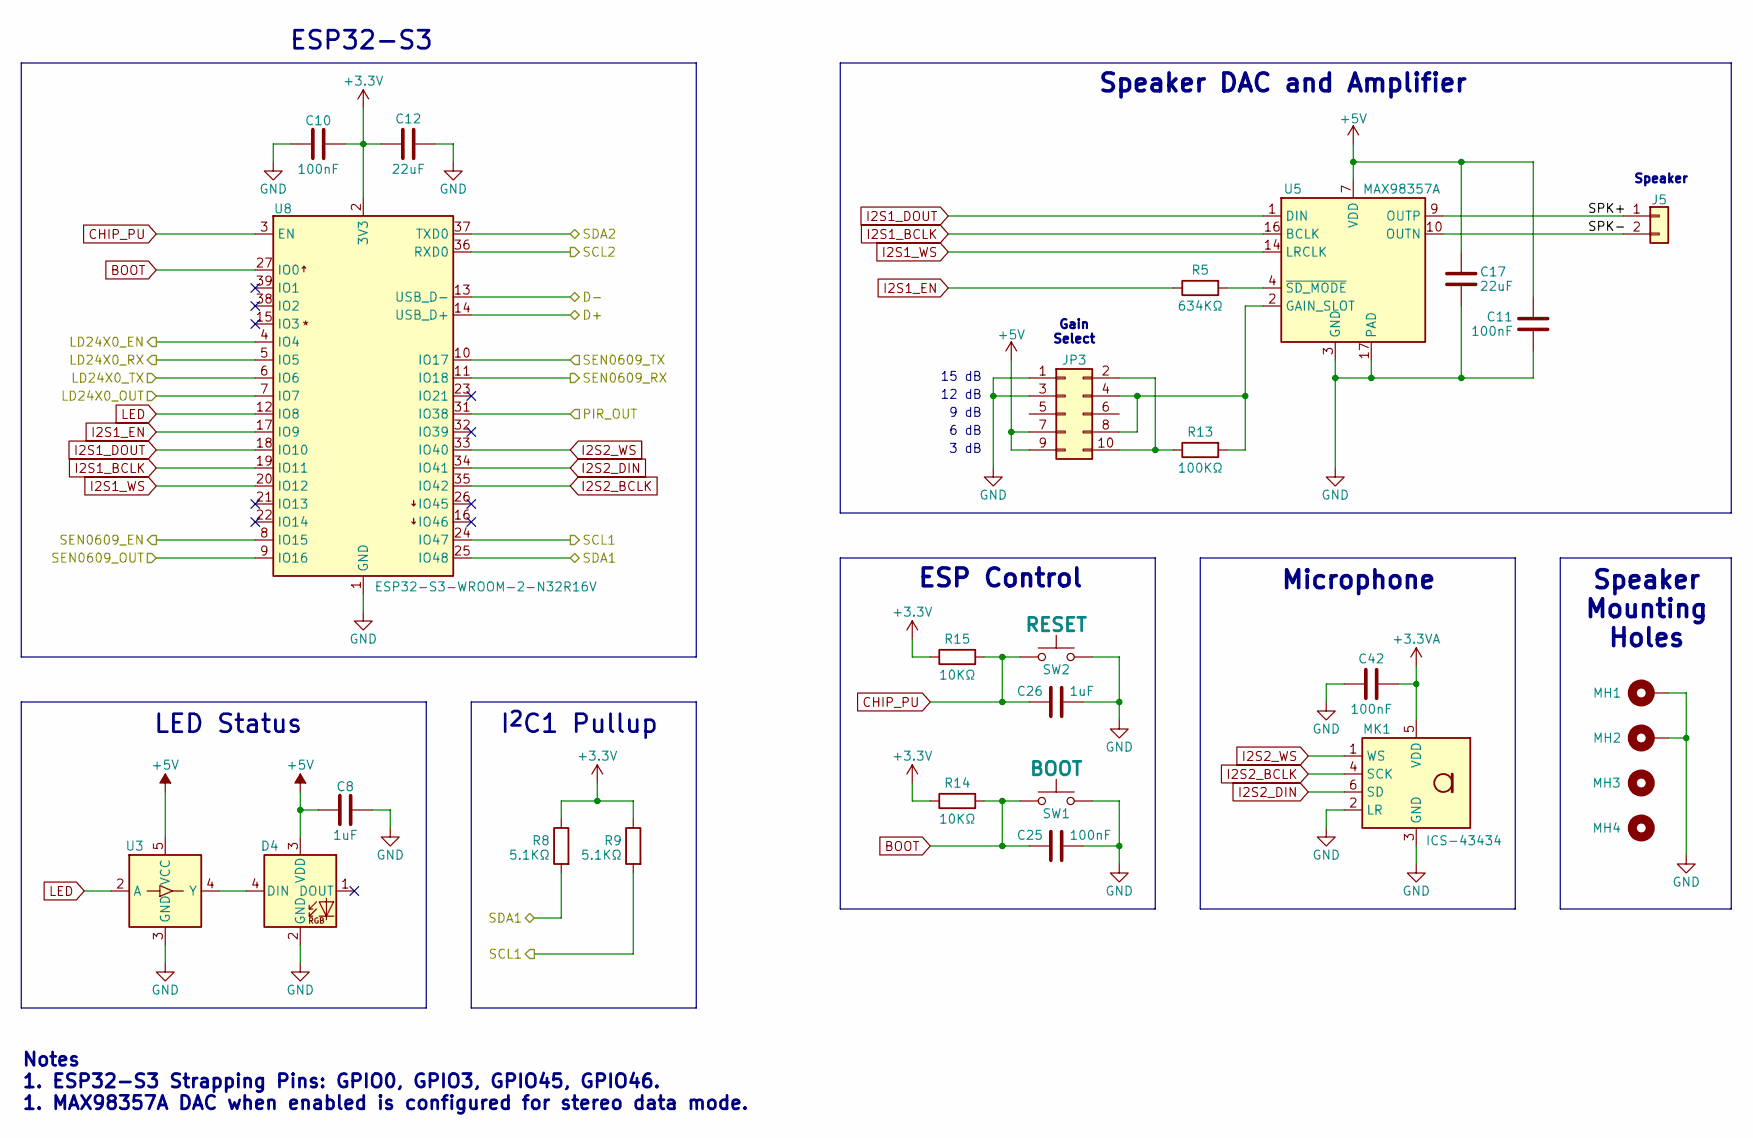
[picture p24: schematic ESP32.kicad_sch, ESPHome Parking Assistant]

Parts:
C8, C26: 1uF; C_0402_1005Metric; Part Number CL05A105KA5NQNC
C10, C11, C25, C42: 100nF; C_0402_1005Metric; Part Number CL05B104KB54PNC
C12, C17: 22uF; C_0603_1608Metric; Part Number GRM188R60J226MEA0D
D4: NeoPixel_THT; LED_D5.0mm-4_RGB; Part Number 1938
J5: SPKR; PinHeader_1x02_P2.00mm_Vertical; Part Number CMS-251437-24SP-X8
JP3: Gain; SAMTEC_TMM-105-01-X-D-SM; Part Number TMM-105-01-L-D-SM-P-TR
MH1, MH2, MH3, MH4: MountingHole_2.2mm_M2_Pad
MK1: ICS-43434; InvenSense_ICS-43434-6_3.5x2.65mm; Part Number ICS-43434
R5: 634KΩ; R_0402_1005Metric; Part Number CRCW0402634KFKED
R8, R9: 5.1KΩ; R_0402_1005Metric; Part Number CRCW04025K10FKED
R13: 100KΩ; R_0402_1005Metric; Part Number CRCW0402100KFKED
R14, R15: 10KΩ; R_0402_1005Metric; Part Number CRCW040210K0FKED
SW1: BOOT; SW_SPST_B3U-1000P-B; Part Number B3U-1000P
SW2: RESET; SW_SPST_B3U-1000P-B; Part Number B3U-1000P
U3: SN74LV1T34DBV; SOT-23-5; Part Number SN74LV1T34DBV
U5: MAX98357A; TQFN-16-1EP_3x3mm_P0.5mm_EP1.23x1.23mm; Part Number MAX98357AETE
U8: ESP32-S3-WROOM-2-N32R16V; ESP32-S3-WROOM-2; Part Number ESP32-S3-WROOM-2-N32R16V

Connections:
+3.3V: C10.2, C12.1, R8.1, R9.1, R14.1, R15.1, U8.2 (3V3); also elsewhere on the board
+3.3VA: C42.2, MK1.5 (VDD); also elsewhere on the board
+5V: C8.1, C11.1, C17.1, D4.3 (VDD), JP3.7, JP3.9, U3.5 (VCC), U5.7 (VDD), U5.8 (VDD); also elsewhere on the board
/D+: U8.14 (USB_D+); also elsewhere on the board
/D-: U8.13 (USB_D-); also elsewhere on the board
/ESP32-S3/SPK+: J5.1, U5.9 (OUTP)
/ESP32-S3/SPK-: J5.2, U5.10 (OUTN)
/LD24X0_EN: U8.4 (IO4); also elsewhere on the board
/LD24X0_OUT: U8.7 (IO7); also elsewhere on the board
/LD24X0_RX: U8.5 (IO5); also elsewhere on the board
/LD24X0_TX: U8.6 (IO6); also elsewhere on the board
/PIR_OUT: U8.31 (IO38); also elsewhere on the board
/SCL1: R9.2, U8.24 (IO47); also elsewhere on the board
/SCL2: U8.36 (RXD0); also elsewhere on the board
/SDA1: R8.2, U8.25 (IO48); also elsewhere on the board
/SDA2: U8.37 (TXD0); also elsewhere on the board
/SEN0609_EN: U8.8 (IO15); also elsewhere on the board
/SEN0609_OUT: U8.9 (IO16); also elsewhere on the board
/SEN0609_RX: U8.11 (IO18); also elsewhere on the board
/SEN0609_TX: U8.10 (IO17); also elsewhere on the board
BOOT: C25.2, R14.2, SW1.2, U8.27 (IO0)
CHIP_PU: C26.1, R15.2, SW2.2, U8.3 (EN)
GND: C8.2, C10.1, C11.2, C12.2, C17.2, C25.1, C26.2, C42.1, D4.2 (GND), JP3.1, JP3.3, MH1.1, MH2.1, MK1.2 (LR), MK1.3 (GND), SW1.1, SW2.1, U3.3 (GND), U5.3 (GND), U5.11 (GND), U5.15 (GND), U5.17 (PAD), U8.1 (GND), U8.40 (GND), U8.41 (GND); also elsewhere on the board
I2S1_BCLK: U5.16 (BCLK), U8.19 (IO11)
I2S1_DOUT: U5.1 (DIN), U8.18 (IO10)
I2S1_EN: R5.1, U8.17 (IO9)
I2S1_WS: U5.14 (LRCLK), U8.20 (IO12)
I2S2_BCLK: MK1.4 (SCK), U8.35 (IO42)
I2S2_DIN: MK1.6 (SD), U8.34 (IO41)
I2S2_WS: MK1.1 (WS), U8.33 (IO40)
LED: U3.2 (A), U8.12 (IO8)
unnamed: D4.4 (DIN), U3.4 (Y)
unnamed: JP3.4, JP3.8, R13.2, U5.2 (GAIN_SLOT)
unnamed: JP3.2, JP3.10, R13.1
unnamed: R5.2, U5.4 (~SD_MODE)

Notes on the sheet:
12 dB
3 dB
Speaker
Gain Select
I^{2}C1 Pullup
9 dB
15 dB
ESP32-S3
6 dB
Speaker Mounting Holes
Notes 1. ESP32-S3 Strapping Pins: GPIO0, GPIO3, GPIO45, GPIO46. 1. MAX98357A DAC when enabled is configured for stereo data mode.
Speaker DAC and Amplifier
ESP Control
Microphone
LED Status

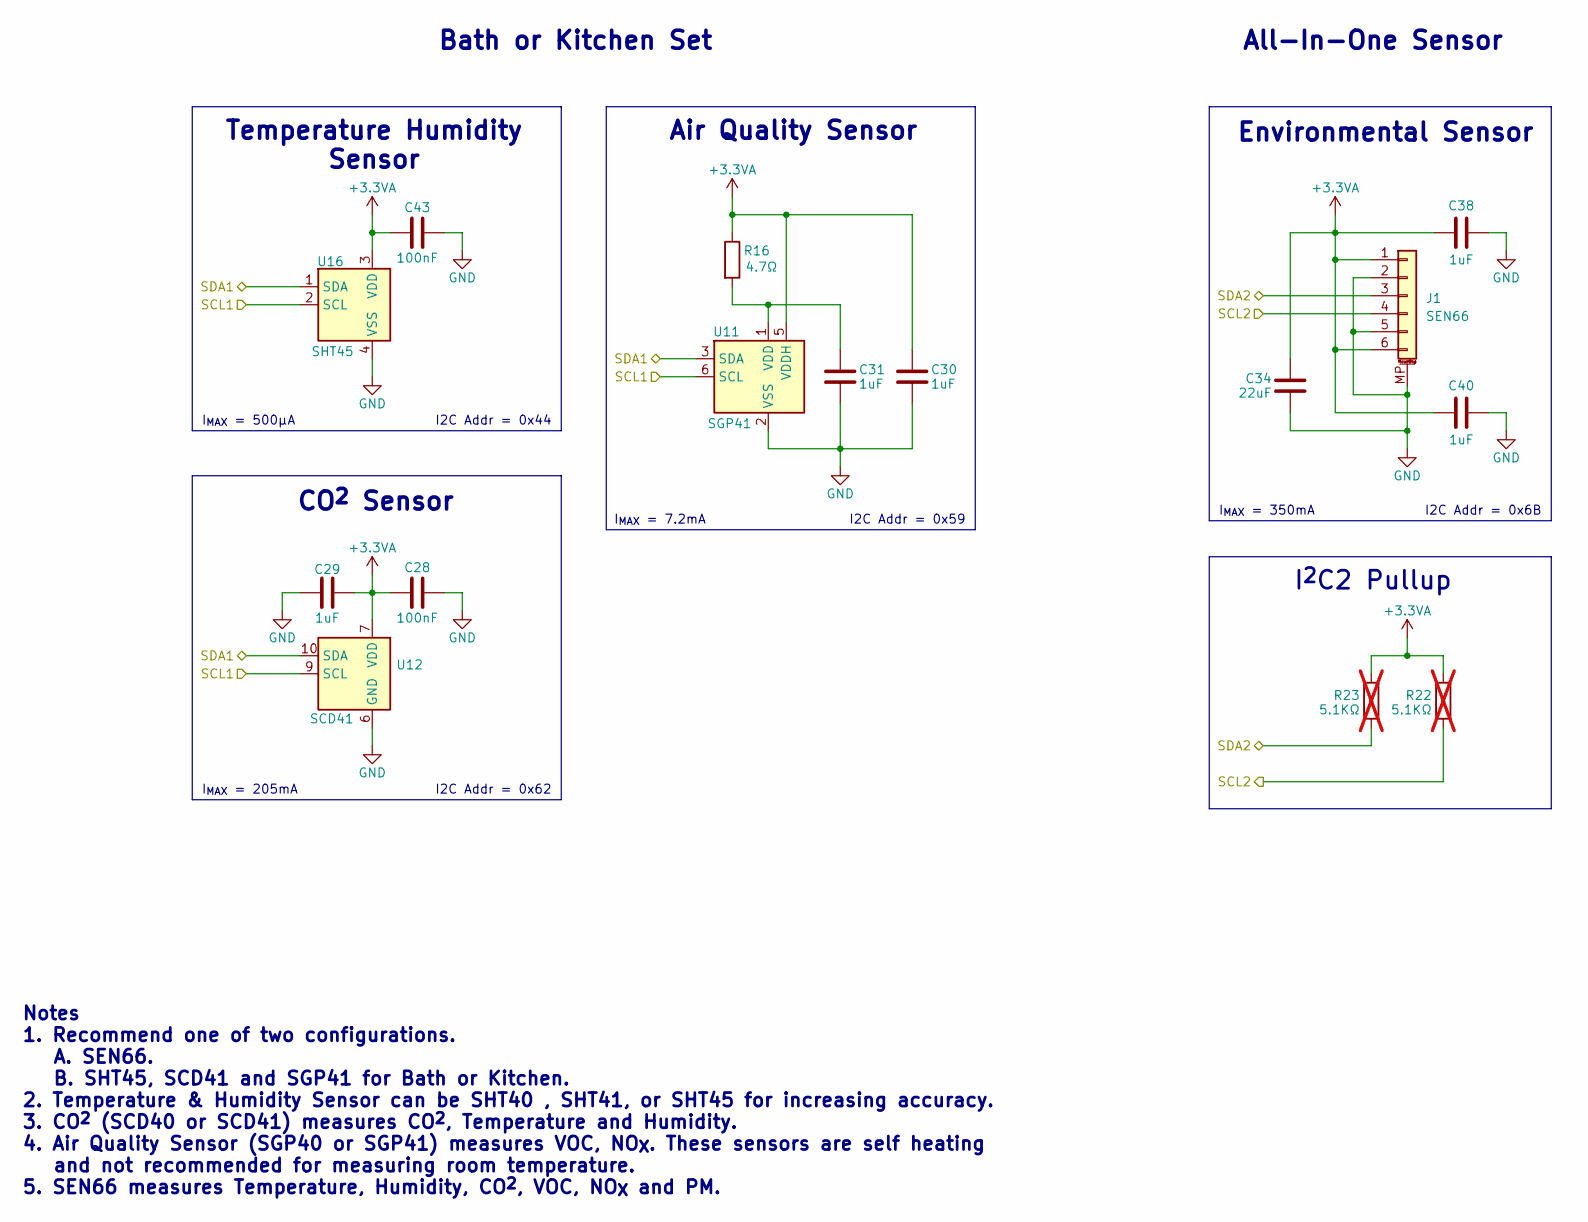
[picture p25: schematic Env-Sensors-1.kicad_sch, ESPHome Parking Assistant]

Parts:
C28, C43: 100nF; C_0402_1005Metric; Part Number CL05B104KB54PNC
C29, C30, C31, C38, C40: 1uF; C_0402_1005Metric; Part Number CL05A105KA5NQNC
C34: 22uF; C_0603_1608Metric; Part Number GRM188R60J226MEA0D
J1: SEN66; JST_GH_BM06B-GHS-TBT_1x06-1MP_P1.25mm_Vertical; Part Number BM06B-GHS-TBT
R16: 4.7Ω; R_0402_1005Metric; Part Number CRCW04024R70FKED
R22, R23: 5.1KΩ; R_0402_1005Metric; Part Number CRCW04025K10FKED; not fitted
U11: SGP41; XCDR_SGP40-D-R4; Part Number SGP41-D-R4
U12: SCD41; Sensirion_SCD4x-1EP_10.1x10.1mm_P1.25mm_EP4.8x4.8mm; Part Number SCD41-D-R2
U16: SHT45; Sensirion_DFN-4_1.5x1.5mm_P0.8mm_SHT4x_NoCentralPad; Part Number SHT45-AD1B-R2

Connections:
+3.3VA: C28.2, C29.2, C30.1, C34.1, C38.1, C40.1, C43.2, J1.1, J1.6, R16.1, R22.1, R23.1, U11.5 (VDDH), U12.7 (VDD), U12.19 (VDD), U16.3 (VDD); also elsewhere on the board
/SCL1: U11.6 (SCL), U12.9 (SCL), U16.2 (SCL); also elsewhere on the board
/SCL2: J1.4, R22.2; also elsewhere on the board
/SDA1: U11.3 (SDA), U12.10 (SDA), U16.1 (SDA); also elsewhere on the board
/SDA2: J1.3, R23.2; also elsewhere on the board
GND: C28.1, C29.1, C30.2, C31.2, C34.2, C38.2, C40.2, C43.1, J1.2, J1.5, J1.MP (MountPin), U11.2 (VSS), U11.4 (NA), U11.7 (EP), U12.6 (GND), U12.20 (GND), U12.21 (GND), U16.4 (VSS); also elsewhere on the board
unnamed: C31.1, R16.2, U11.1 (VDD)

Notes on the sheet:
I_{MAX} = 7.2mA
I2C Addr = 0x59
I2C Addr = 0x62
CO^{2} Sensor
Environmental Sensor
I_{MAX} = 350mA
I^{2}C2 Pullup
Temperature Humidity Sensor
All-In-One Sensor
Bath or Kitchen Set
I2C Addr = 0x44
I2C Addr = 0x6B
I_{MAX} = 500µA
I_{MAX} = 205mA
Notes 1. Recommend one of two configurations. A. SEN66. B. SHT45, SCD41 and SGP41 for Bath or Kitchen. 2. Temperature & Humidity Sensor can be SHT40 , SHT41, or SHT45 for increasing accuracy. 3. CO^{2} (SCD40 or SCD41) measures CO^{2}, Temperature and Humidity. 4. Air Quality Sensor (SGP40 or SGP41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
Air Quality Sensor

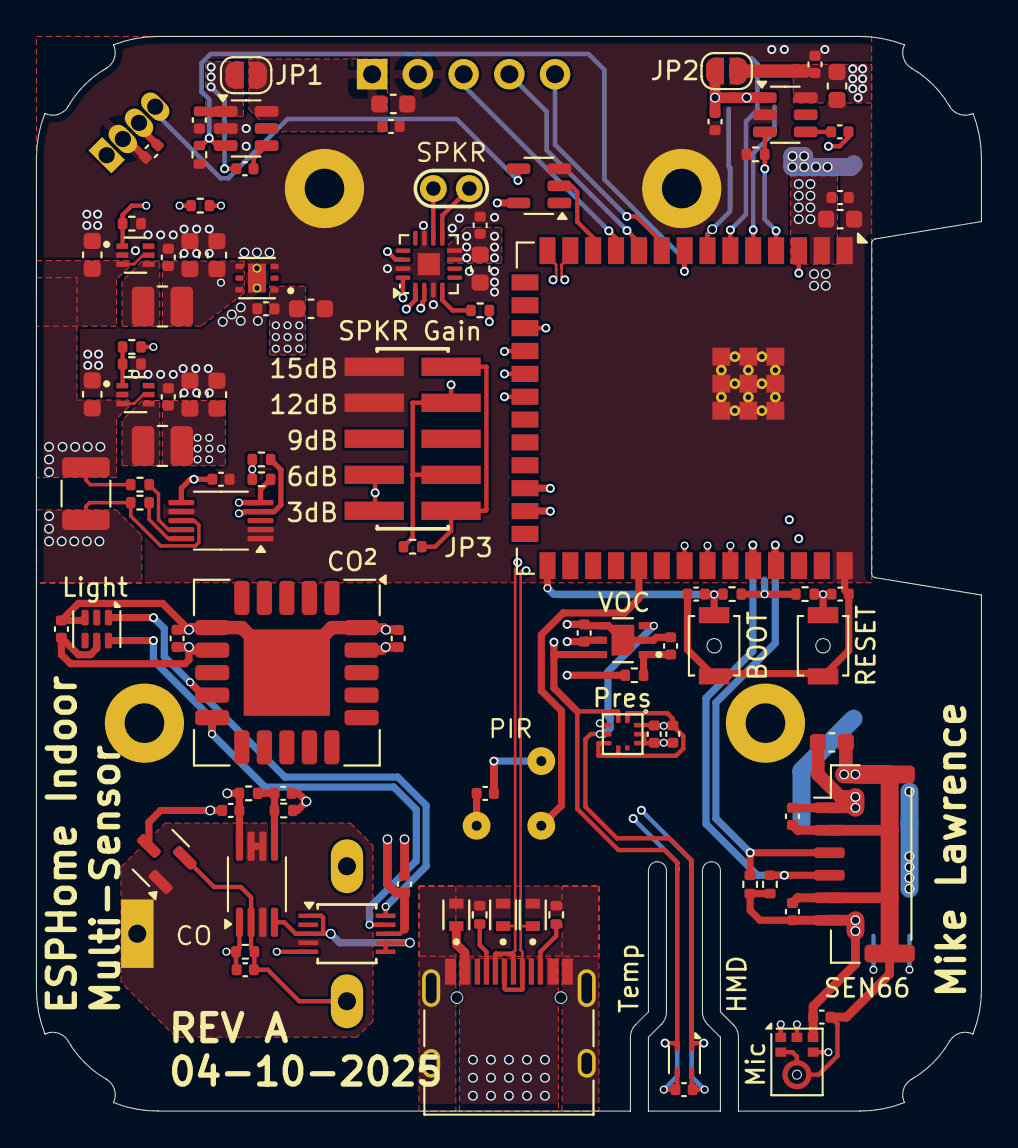
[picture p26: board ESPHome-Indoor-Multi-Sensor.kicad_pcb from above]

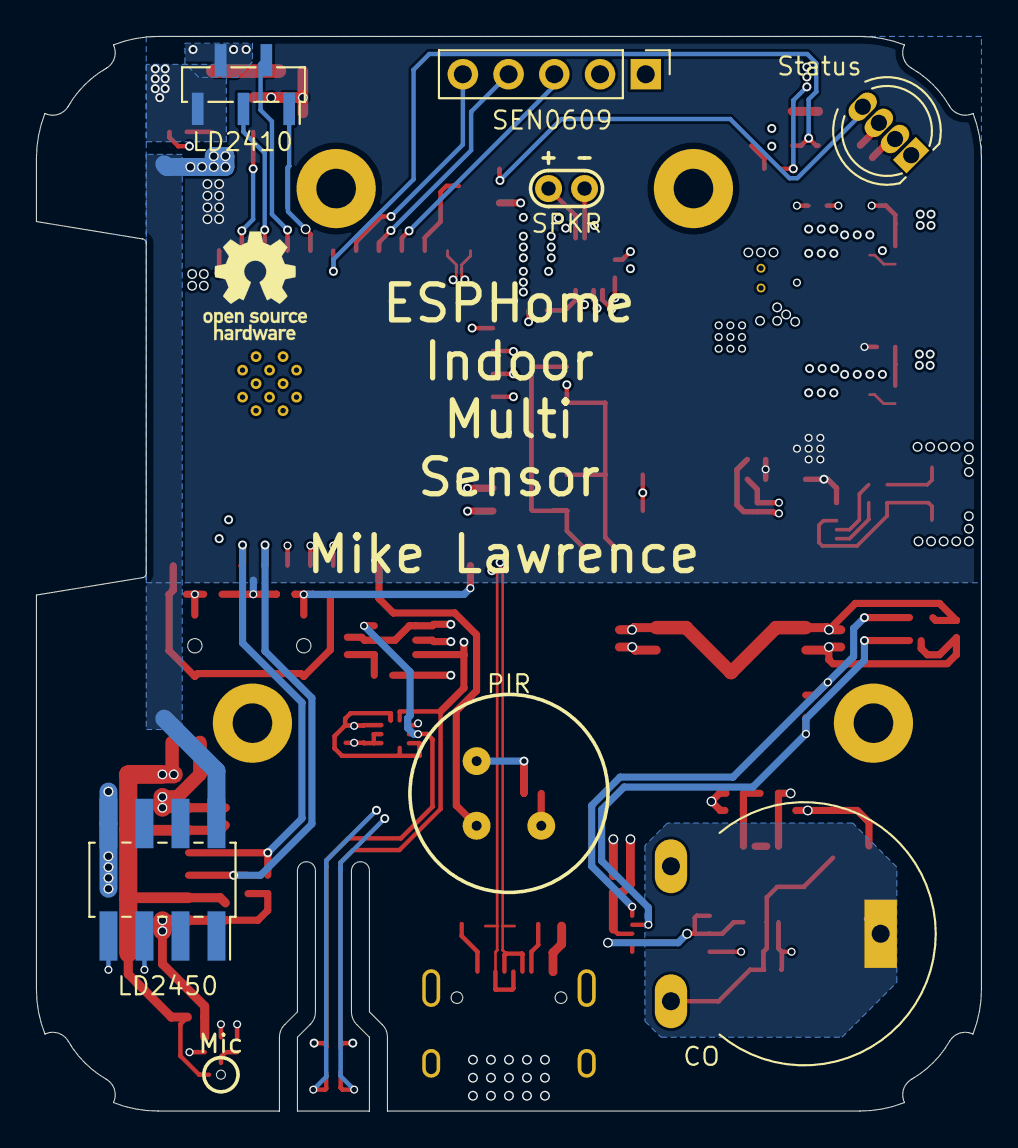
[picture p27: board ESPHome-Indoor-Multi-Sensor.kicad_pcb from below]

Board: 4 copper layers, 52.5 x 59.7 mm, 108 parts (8 on the bottom side), 54 nets.

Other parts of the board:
TEXT1: OSHW-Logo_5.7x6mm_SilkScreen

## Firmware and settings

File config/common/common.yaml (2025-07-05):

# common setup for all devices

esphome:
  name: ${name}
  friendly_name: ${friendly_name}
  name_add_mac_suffix: true
  on_boot:
    - priority: -100
      then:
        - script.execute: update_status_led
  on_shutdown:
    - priority: 700
      then:
        - light.turn_off:
            id: led_status

# ESP32-S3-WROOM-2-N32R16V
# should support 32MB, but doesn't seem to work
esp32:
  board: esp32s3box
  variant: ESP32S3
  flash_size: 16MB
  cpu_frequency: 240MHz
  framework:
    type: esp-idf

# This PSRAM can actually support faster than 80MHz
psram:
  mode: octal
  speed: 80MHz

# To be able to get logs from the device via serial and api
logger:
  id: logger_common
  level: DEBUG

# All but the SEN6X is on this bus
i2c:
  - id: i2c1_bus
    sda: GPIO48
    scl: GPIO47
    frequency: 400kHz
    scan: true

# audio DAC for speaker
i2s_audio:
  - id: speaker_i2s
    i2s_lrclk_pin: GPIO12
    i2s_bclk_pin: GPIO11

# WiFI AP, required when allowing user to provision WiFi credentials
wifi:
  ap:

# Fallback when WiFi configuration fails
# required when allowing user to provision WiFi credentials using WiFi
captive_portal:

# Allows user to provision WiFi credentials with Bluetooth using Improv standard
esp32_improv:
  authorizer: none

# Allow user to provision WiFi credentials with USB port using Improv standard
improv_serial:

esp32_ble_tracker:
  scan_parameters:
    active: true

bluetooth_proxy:
  active: true

debug:
  update_interval: 60s

web_server:
  port: 80

time:
  - platform: homeassistant
    id: homeassistant_time

script:
  - id: update_status_led
    mode: restart
    then:
      lambda: |-
        static bool last_state;
        static float last_r, last_g, last_b, last_brightness = ${status_night_brightness};
        bool state;
        float r, g, b, brightness = last_brightness;
        if(last_brightness == ${status_day_brightness}) {
          // daytime
          if(id(lux).state < ${status_nighttime_lux}) {
            brightness = ${status_night_brightness};
            ESP_LOGD("status", "Status LED switched to nighttime brightness");
          }
        } else {
          // nighttime
          if(id(lux).state > ${status_daytime_lux}) {
            brightness = ${status_day_brightness};
            ESP_LOGD("status", "Status LED switched to daytime brightness");
          }
        }
        if(!id(led_enable).state) {
          state = false;
        } else {
          if (id(presence).state) {
            state = true;
            r = 0.0; g = 0.0; b = 1.0;
          } else {
            state = false;
          }
        }
        if (state == false) {
          if (last_state == true) {
            id(led_status).turn_off().set_transition_length(0).perform();
            ESP_LOGD("status", "Status LED turned off");
          }
        } else {
          if ((last_state == false) || (last_r != r) || (last_g != g) ||
              (last_b != b) || (last_brightness != brightness)) {
            id(led_status).turn_on().set_transition_length(0).
              set_rgb(r, g, b).set_brightness(brightness).perform();
            ESP_LOGD("status", "Status LED turned on");
          }
        }
        last_state = state;
        last_brightness = brightness;
        last_r = r;
        last_g = g;
        last_b = b;

binary_sensor:
  - platform: template
    name: Presence
    id: presence
    device_class: presence
    lambda: |-
      if(id(presence_mmwwave).state or
        (id(pir_enable).state && id(motion_pir).state)) {
        return true;
      } else {
        return false;
      }
    on_state:
      then:
        script.execute: update_status_led
  - platform: gpio
    id: motion_pir
    name: PIR Motion
    device_class: motion
    pin:
      number: GPIO38
    filters:
      - delayed_off: !lambda "return id(internal_timeout).state;"

button:
  - platform: restart
    name: "Restart"
    entity_category: CONFIG

light:
  - platform: esp32_rmt_led_strip
    id: led_status
    rgb_order: RGB
    pin: GPIO8
    num_leds: 1
    chipset: ws2812

media_player:
  - platform: speaker
    name: "Speaker Media Player"
    id: speaker_media_player_id
    media_pipeline:
      speaker: media_spk_resampling_input
      num_channels: 2
    announcement_pipeline:
      speaker: announcement_spk_resampling_input
      num_channels: 1

power_supply:
  # Enable audio DAC Power
  - id: dac_enable
    pin: GPIO9
    enable_on_boot: true

sensor:
  - platform: debug
    free:
      name: "Heap Free"
    block:
      name: "Heap Max Block"
    loop_time:
      name: "Loop Time"
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

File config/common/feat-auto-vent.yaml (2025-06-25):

# Add Automatic Vent Control
esphome:
  on_boot:
    then:
      - binary_sensor.template.publish:
          id: vent_auto_hum
          state: false
      - binary_sensor.template.publish:
          id: vent_auto_co2
          state: false
      - binary_sensor.template.publish:
          id: vent_manual
          state: false

binary_sensor:
  - platform: template
    name: "Vent Auto Hum"
    id: vent_auto_hum
  - platform: template
    name: "Vent Auto CO₂"
    id: vent_auto_co2
  - platform: template
    name: "Vent Manual"
    id: vent_manual

#   Uses humidity, VOC and CO₂ to control a bathroom vent
sensor:
  # Long'ish humidity average
  - platform: copy
    id: humidity_long_avg
    source_id: humidity_internal
    unit_of_measurement: "%"
    accuracy_decimals: 2
    filters:
      - lambda: |-
          static bool first = true;
          static float long_avg;
          static float alpha = 0.003;
          // handle initialization
          if (first) {
            if (!isnan(x)) {
              long_avg = x;
              first = false;
              ESP_LOGD("auto_vent", "Humidity Long Average, alpha = %f", alpha);
              return long_avg;
            } else {
              return x;
            }
          } else if (isnan(x)) {
            return long_avg;
          }
          // compute Exponential Moving Average
          long_avg = alpha * x + (1 - alpha) * long_avg;
          return long_avg;

  # Short'ish humidity average
  - platform: copy
    id: humidity_short_avg
    source_id: humidity_internal
    unit_of_measurement: "%"
    accuracy_decimals: 2
    filters:
      - lambda: |-
          static bool first = true;
          static float short_avg;
          static float alpha = 0.09;
          // handle initialization
          if (first) {
            if (!isnan(x)) {
              short_avg = x;
              first = false;
              ESP_LOGD("auto_vent", "Humidity Short Average, alpha = %f", alpha);
              return short_avg;
            } else {
              return x;
            }
          } else if (isnan(x)) {
            return short_avg;
          }
          // compute Exponential Moving Average
          short_avg = alpha * x + (1 - alpha) * short_avg;
          id(update_vent_state_machine).execute();
          return short_avg;

switch:
  - platform: homeassistant
    id: ha_vent
    entity_id: ${vent_ha_entity}
    on_turn_on:
      - script.execute: update_vent_state_machine
    on_turn_off:
      - script.execute: update_vent_state_machine
script:
  - id: update_vent_state_machine
    mode: restart
    then:
      lambda: |-
        static bool first = true;
        static int state = 0;
        static unsigned long start_time;
        constexpr const char *const ESP_LOG_TAG = "auto_vent";
        constexpr const char *const ESP_LOG_MSG_HIGH_HUM = "Detected high humidity";
        constexpr const char *const ESP_LOG_MSG_HIGH_CO₂ = "Detected high CO₂";
        constexpr const char *const ESP_LOG_MSG_MAN_OFF = "Manually turned off, turning back on";
        float on_time_seconds;
        float co2_value = 0;
        float hum = id(humidity_internal)->state;
        float hum_long_avg = id(humidity_long_avg)->state;
        float hum_short_avg = id(humidity_short_avg)->state;
        // handle initialization
        if (first) {
          first = false;
        }
        // grab co2 if we are controlling the fan for co2 too
        if (${vent_use_co2}) {
          co2_value = id(co2)->state;
        }
        if (state != 0) {
          on_time_seconds = round(static_cast<float>(millis() - start_time) / 1000.0);
        } else {
          on_time_seconds = 0.0;
        }
        // compute conditions
        bool humidity_is_high = (hum - hum_long_avg >= ${vent_hum_on_trigger}) && ${vent_use_humidity};
        bool humidity_is_low = ((hum - hum_long_avg <= ${vent_hum_off_trigger})
          && (hum_short_avg - hum_long_avg <= ${vent_hum_off_trigger})) || ${vent_use_humidity};
        bool vent_on_min_time = on_time_seconds >= static_cast<float>(${vent_min_on_time} * 60);
        bool co2_is_high = co2_value >= ${vent_co2_on_trigger} && ${vent_use_co2};
        bool co2_is_low = co2_value <= ${vent_co2_off_trigger} || ${vent_use_co2};
        // State Machine
        switch (state) {
        // Idle State
        case 0:
          if (humidity_is_high) {
            ESP_LOGD(ESP_LOG_TAG,  ESP_LOG_MSG_HIGH_HUM);
            start_time = millis();
            id(ha_vent).turn_on();
            id(vent_auto_hum).publish_state(true);
            state = 10;
          } else if (co2_is_high) {
            ESP_LOGD(ESP_LOG_TAG,  "Detected high CO₂");
            id(ha_vent).turn_on();
            id(vent_auto_co2).publish_state(true);
            state = 60;
          } else if (id(ha_vent).state == true) {
            ESP_LOGD(ESP_LOG_TAG,  "Manually turned on");
            start_time = millis();
            id(vent_manual).publish_state(true);
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

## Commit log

2025-04-11 Initial commit.
    [55510-308TRLF--3DModel-STEP-554624.STEP, 5mm RGB LED--3DModel-STEP-269445.STEP, 791091003.stp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]
2025-04-12 Round out the enclosure section.
    [ESPHome-Multi-Sensor-Enclosure Back Body.step, ESPHome-Multi-Sensor-Enclosure Front Body.step, ESPHome-Multi-Sensor-Enclosure-Back-Mount-10°.step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]
2025-04-12 Cleanup the PCB section.
2025-04-12 SLight change to schematic.
    [ESPHome-Indoor-Multi-Sensor.kicad_sch, Env-Sensors-1.kicad_sch]
2025-06-11 Minor changes
    Separate SEN66 on a separate I2C bus.
    Add WIFi Antenna cutout.
    Beef-up Power and Ground connections to SEN66.
    [ESP32.kicad_sch, ESPHome-Indoor-Muiti-Sensor-BOM.csv, ESPHome-Indoor-Muiti-Sensor-BOM.xlsx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]
2025-06-30 Workflow updates
    Add automatic Release when merging a pull request into main.
    Next the ESP32 build process is kicked off for all config files.
    Next the build files are published to the Release as assets.
    And finally Github Pages are published supporting the new Release.
2025-06-30 Substantial config changes
    Config filenames now include esp32-s3.
    Simplification of substitutions
2025-06-30 Support External Component 2591
    Fix compile ESP32 compile error
2025-06-30 Changes to TSL2591 configuration
    Looking for better low light and stopping the both sensors are 0 warning
2025-06-30 CO2 changes
    Fix missing update on CO2 Calibration Date Sensor
    Configuration variable changed to automatic_self_calibration which is already in consts.py
2025-07-05 Back to common.yaml file approach (#12)
    * Make sure key sensors have id's
    * Remove condition on create-release workflow
    * Change when to publish co2_calibration_date
    * Update external component source
    * Support updating when API connects for info template text sensors
    * New CO warning alert
    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
2025-07-05 PCB Rev A
    Minor changes to PCB now at Rev A
    [ESPHome-Multi-Sensor-Enclosure-Bambu-Studio.3mf]
2025-07-05 Fix schematic pdf
2025-07-05 Remove BMP581 for external components
    Switching back to ESPHome component

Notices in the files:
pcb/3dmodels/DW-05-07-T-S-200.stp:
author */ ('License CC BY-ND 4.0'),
